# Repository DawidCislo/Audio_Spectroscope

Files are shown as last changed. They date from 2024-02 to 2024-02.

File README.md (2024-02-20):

# Audio_Spectroscope


This is an Audio Spectroscope made without using any kind of programmable devices. It uses over 120 ICs such as operational amplifiers, comparators and logic gates to create the effect you can see in the preview above.

# Theory of operation
The device consists of 11 PCBs, one backplane and 10 display modules. You can find the KiCad project files for the backplane in the 'ASP_Backplane' folder, and files for the display modules in the 'ASP_DIsplay' folder. On the backplane there are 2 3.5mm TRS sockets. Both of them are connected together, and the user can plug the source to one of the sockets, and headphones or speakers to the other, so there's no need to use a splitter. Next using a set of jumpers (JP1, JP2, JP3) the user can use either the left, right or both channels as the input for the spectroscope. Jumpers feed into a preamp with user-adjustable gain (U4A), so both quitet and loud listeners can see the spectroscope work. The series shottky diode (D4) protects the preamp from voltage spikes coming from the audio input and can be omitted.

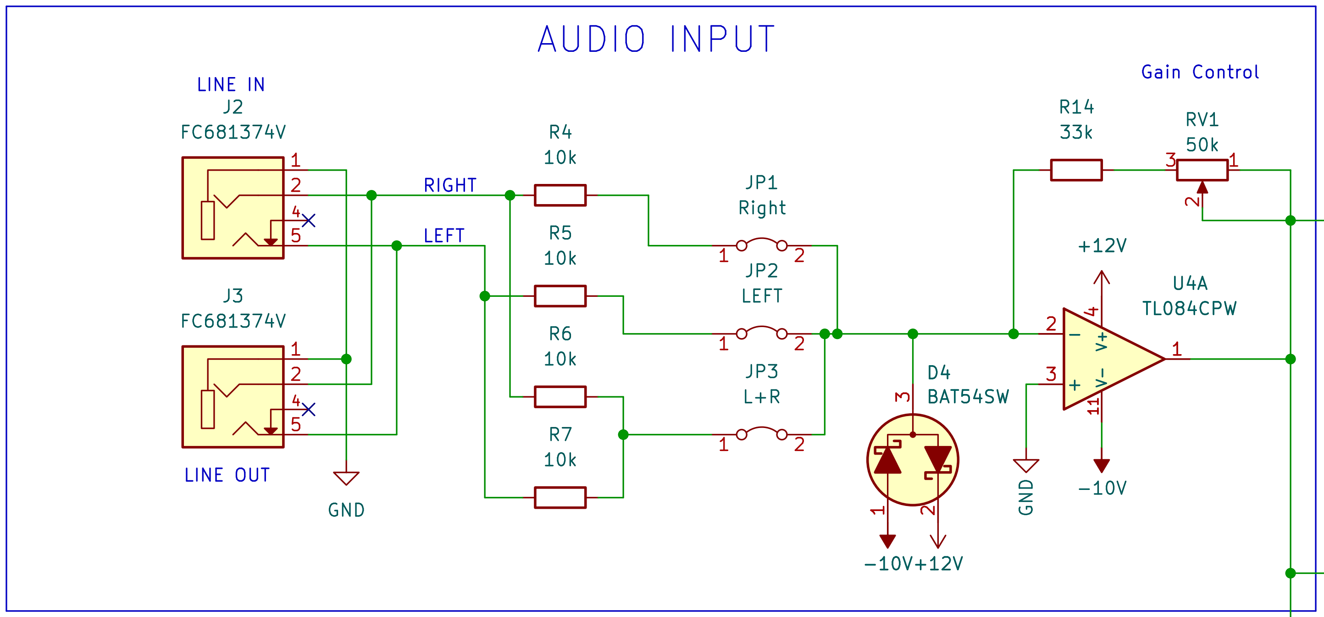
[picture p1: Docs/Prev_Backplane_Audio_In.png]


The preamp feeds into 10 active band-pass filters that separate the audio signals into different bands. Those bands are: 32Hz, 63Hz, 125Hz, 250Hz, 500Hz, 1kHz, 2kHz, 4kHz, 8kHz and 16kHz. Each band is connected to a separate display module connector.

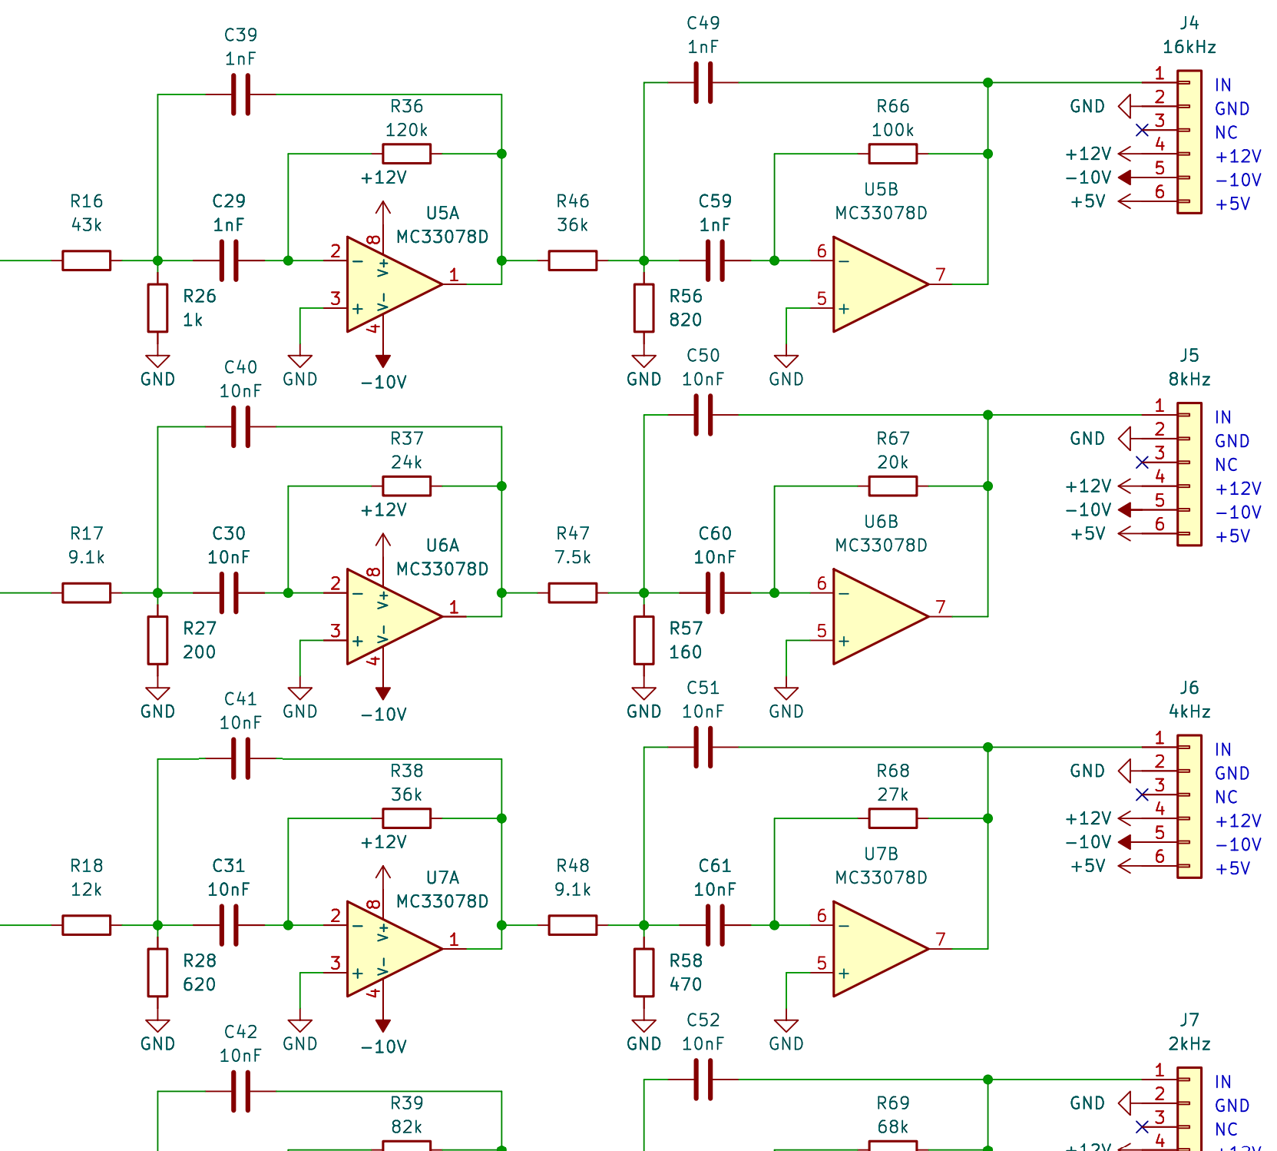
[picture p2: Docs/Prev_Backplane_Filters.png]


The backplane also has a power connector (5.5/2.1mm DC jack, center positive), for use with an external 12V 1A power supply, with a switch and some basic overvoltage protection. You can save on component cost by replacing the power switch (SW1) with a jumper, so that the device will always be on, and you can omit the TVS diode (D1) and replace both the fuse (F1) and reverse-circuit protection diode (D3) with a short - this will reduce resistance to voltage spikes coming from the external power supply.

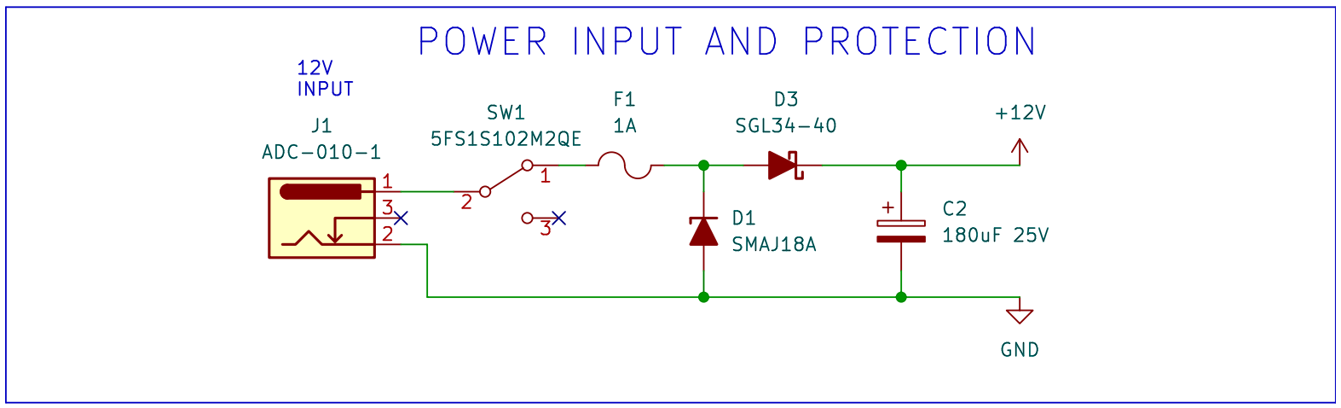
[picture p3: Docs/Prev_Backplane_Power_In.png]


Device uses an LM2576T for generating the 5V rail, the circuit has a voltage divider with resistor values calculated for an adjustable version of LM2576T, but if a fixed 5V version of this IC is available, simply omit R13 during assembly and replace R12 with a short.

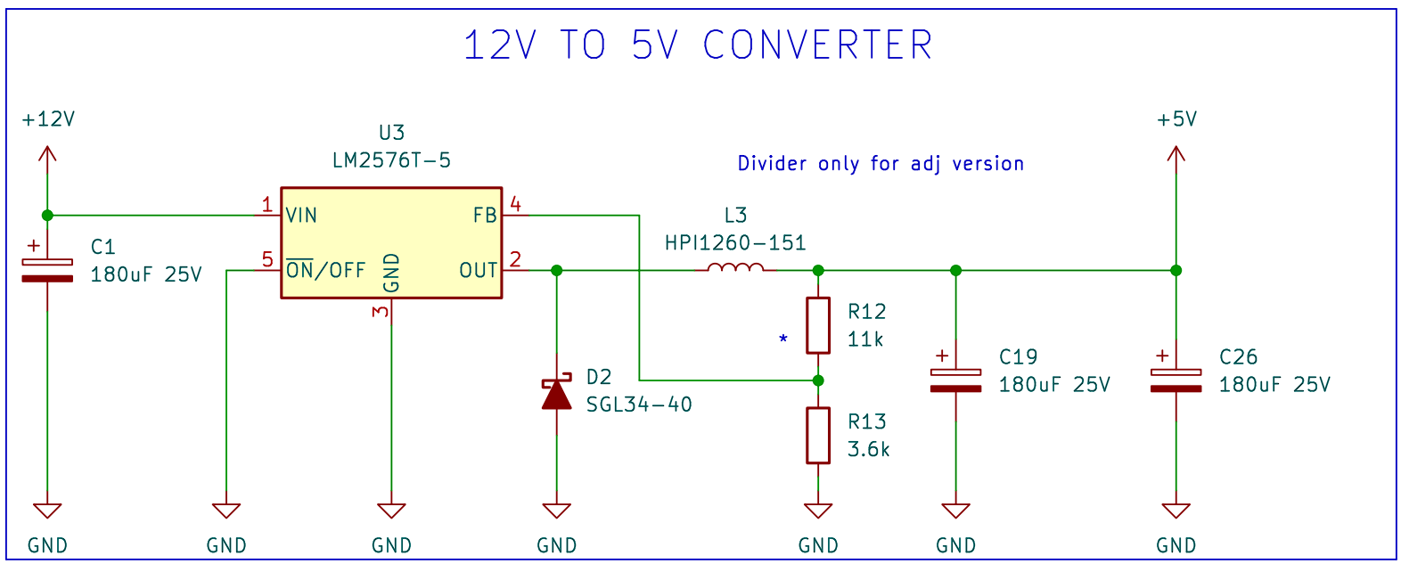
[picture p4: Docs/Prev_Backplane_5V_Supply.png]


Backplane also has a -10V source built using an MC34063 multi-purpose controller. Due to low current draw on the -10V rail, internal switching transistor is sufficient, simplifying the design.

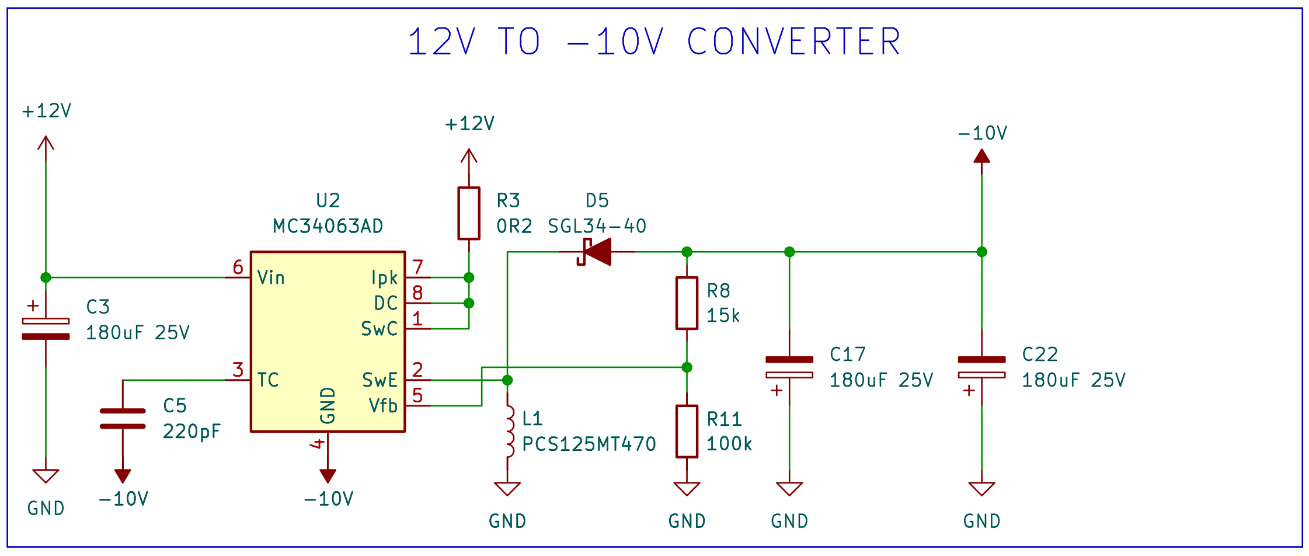
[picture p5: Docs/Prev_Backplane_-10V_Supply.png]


Each display module has two peak detectors connected in series. The first detector made up of U3A, D1 and U3B has a smaller hold capacitor C12 and it's quickly discharged by R34. Output of this peak detector will show the current amplitude of a filtered audio signal. Next peak detector (U3C, D2 U3D) has a larger hold capacitor and it does not have a discharge resistor. Since it's connected to U3D and D2 it will still discharge, because of non-zero leakage currents of those components. Output of this slow peak detector will show the maximum amplitude of the audio signal and hold it there for a short while.

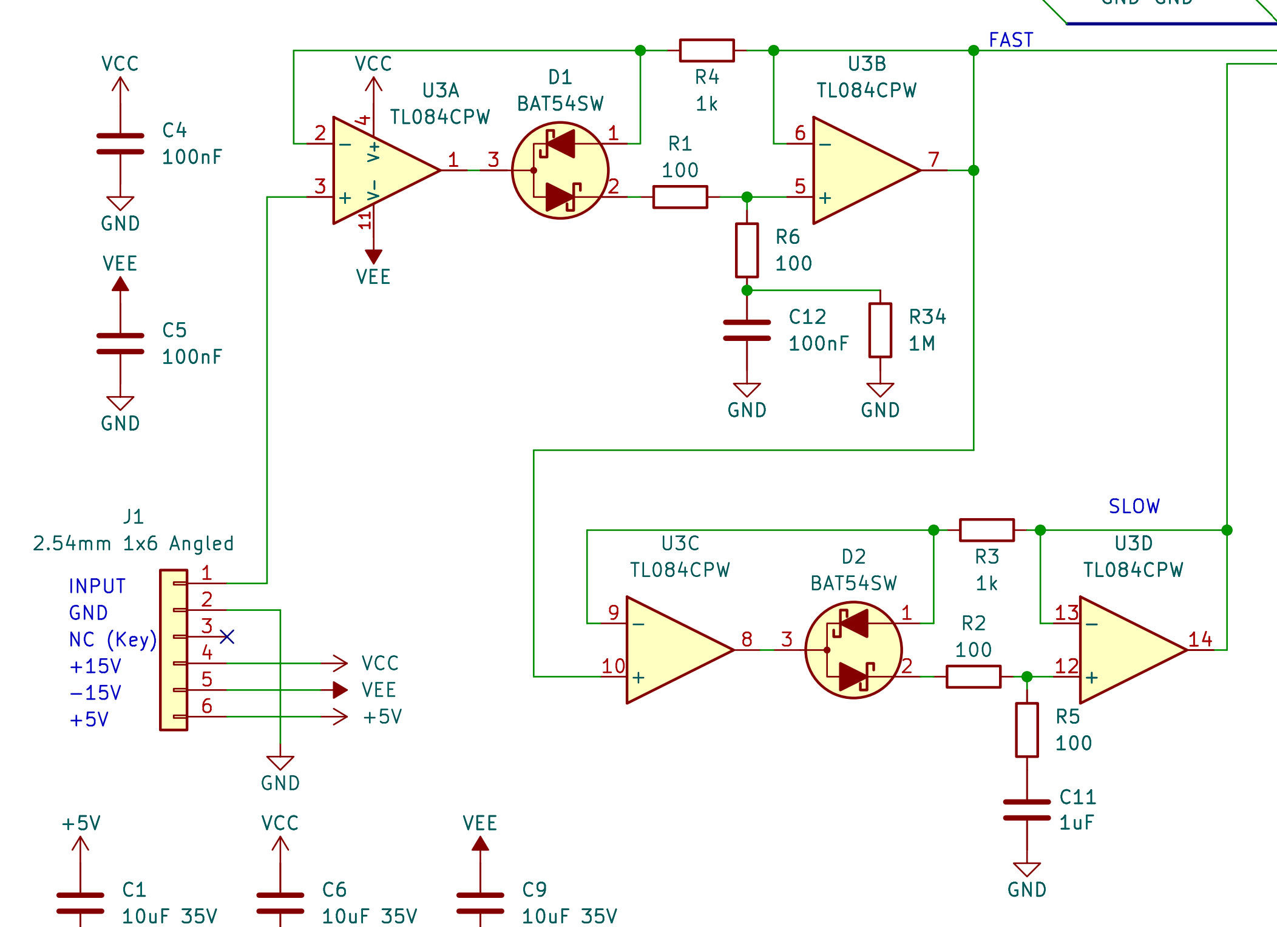
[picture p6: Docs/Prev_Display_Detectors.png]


Both the fast and slow peak detector outputs are connected to 12 comparators each. Reference levels for the comparators are set by a long voltage divider in the middle. If a voltage on the input line is higher than the reference voltage set by the resistors, a comparator pulls the output low (since it has an open-collector output). In effect, the higher the voltage on the input line, the more comparators are switched off, and the more of their outputs have a logic low. On the fast side the comparators connect to logic NOT gates through some simple Resistor-Diode level shifter. On the slow side the comparators feed through voltage level shifters into Ex-OR gates. Each Ex-Or gate is connected to both it's own comparator, and the next comparator. If both of the comparator outputs are the same, the gate's output is low. Only in a situation, when the current level is different from the next one, the gate has a logic 1 on its output. As a result, for example, the fast side outputs '000001111111' while the slow side wil only output '000001000000'. 

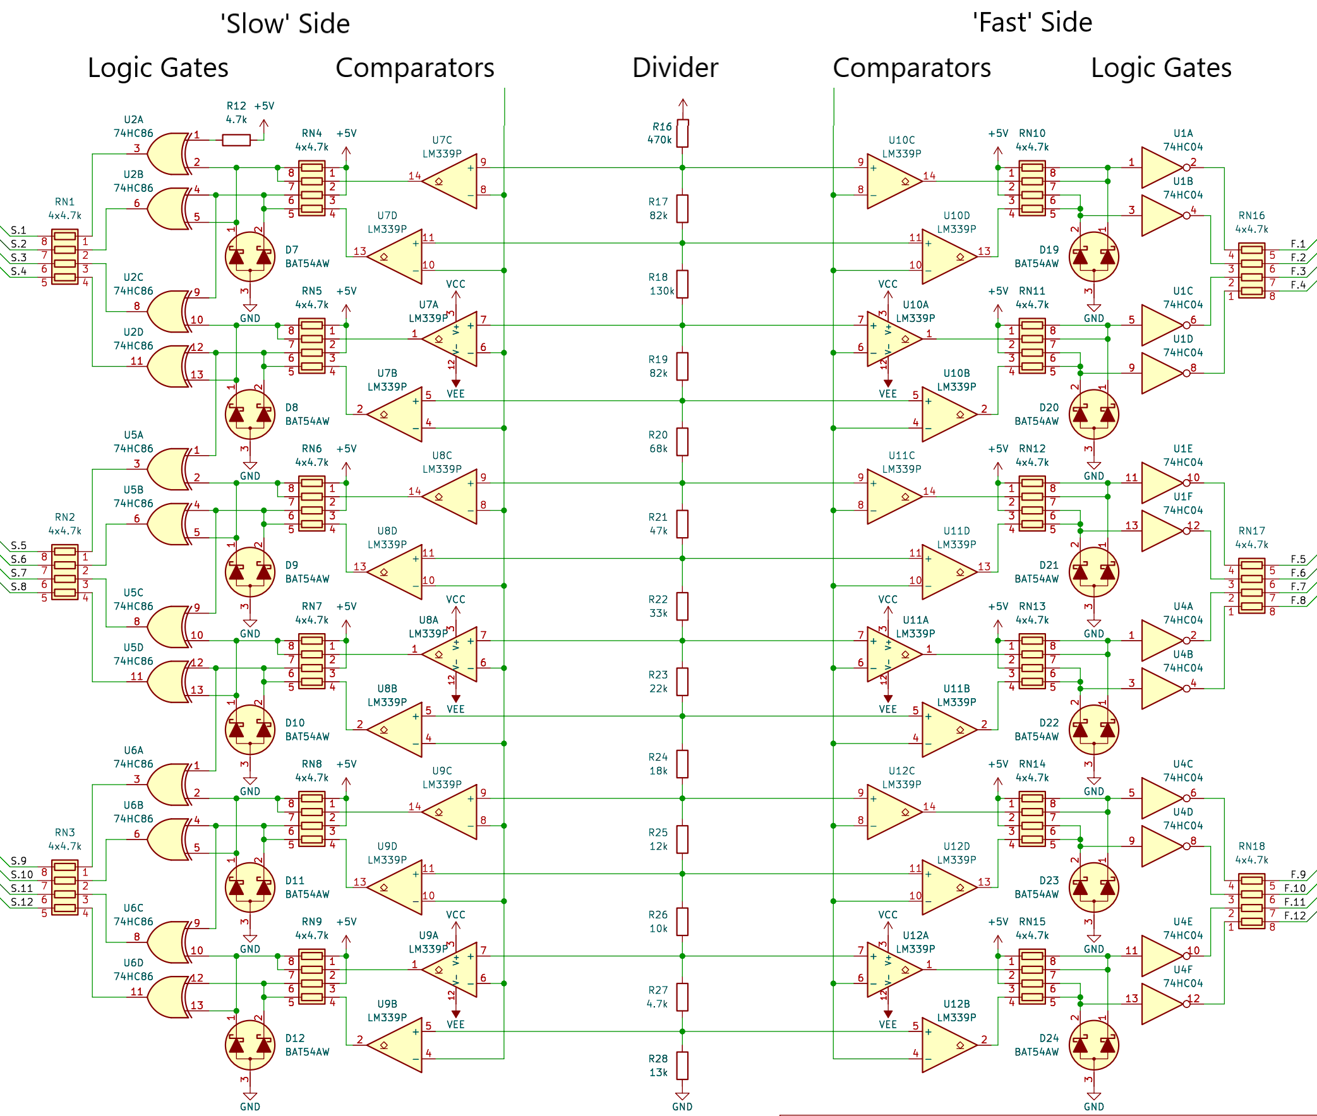
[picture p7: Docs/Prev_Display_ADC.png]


The LEDs are driven by a pair of transistors each (Q2, Q3, Q4 ...). One transistor is controlled by the slow side, while the other one is controlled by the fast side. Transistors are connected in such a way, that either one can independently turn the LED on. Current of the LEDs is set by the series resistors (R8, R9, R10 ...), increasing the value of these resistors decreases the brightness of the LED, and reducing the value increases it. Different LEDs from different manufacturers might need adjustment of these resistor values to achieve a matching brightness for different colors. During the assembly of the first prototype I bought new red and green LEDs, but used old yellow LEDs that I had in stock. Since the old LEDs were much dimmer than the new ones, I used a lower value of resistance for yellow LEDs. Results may vary for your LEDs and it's much better to check them before soldering all 10 display modules.

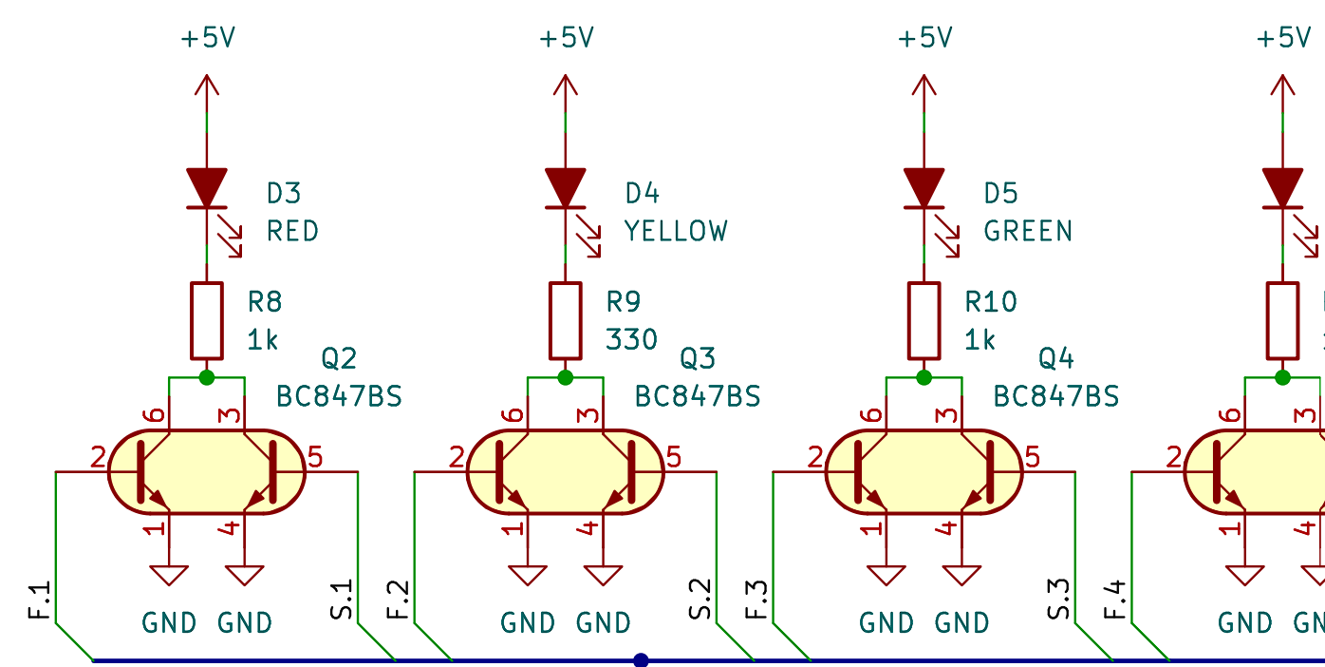
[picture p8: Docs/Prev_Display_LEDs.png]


#  Assembly tips and troubleshooting
>[!CAUTION]
>This device is ***VERY CHALLENGING TO ASSEMBLE*** There is a lot of small and hard to solder components (0603, TSSOP with 0.65mm pin pitch 4x0603 resistor networks, SOT-363s) packed very close together. On top of that there's over 1200 components to solder in total, and it will take very long time to assemble.
I recommend testing every PCB before connecting them together:
- Display modules: Connect all the supply rails on the angled connector to a corresponding voltage source, preferably use a multi-rail adjustable power supply. Next, connect the input of the display module to a potentiometer, generating a voltage between 0V and 5V. See if all the LEDs light up. Next rapidly turn the potentiometer down and see if all the LEDs light up as the slow peak detector discharges. If you see LEDs that are permamently off, check the series resistors and dual transistors next to the LEDs. If whole 4x or 6x sections refuse to light up or stay always on, check the ICs. If single LEDs stay on or light up in the wrong order, check the resistor networks. If the whole module refuses to light up, check the peak detector.
- Backplane: Check if there is no short on any power rails by sticking two pieces of wire into any of the display module connector and using a multimeter in a continuity mode. If there are no shorts on any of the rails, connect the external power supply, and then using the same 2 wires and a multimeter, now in voltage mode, check if all the supply rails have a correct voltage. Note: having a slightly lower voltage on both the 12V and -10V is still fine and will not prevent the device from wirking correctly.
Only after each PCB is thoroughly tested, you can connect them all together and see if the device really works. Display modules are packed very close together, so make sure that the LEDs don't short to the neighbouring modules. Now connect the audio cable and use an online tone generator ([like this one](https://www.szynalski.com/tone-generator/)) to test if the band-pass filters are working correctly.

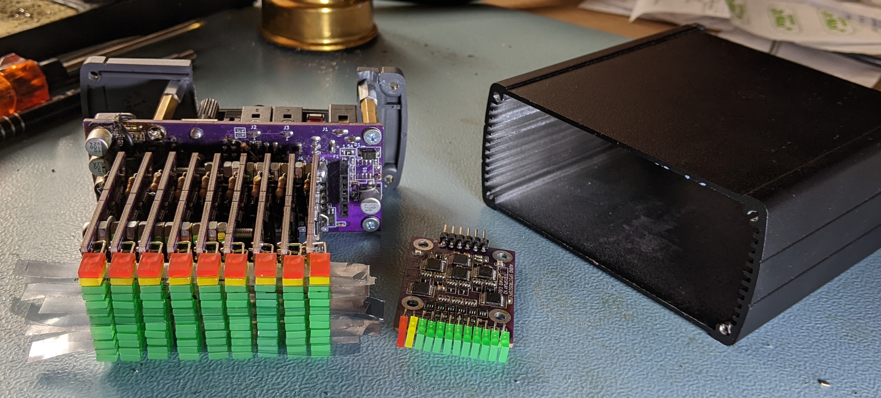
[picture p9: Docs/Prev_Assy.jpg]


If everything is working as it should, you can go ahead and assemble it together. I used a set of long M3 screws to tie all the display modules together and used a [TEKAL 31.29](https://www.tme.eu/pl/details/tekal31.29/obudowy-z-panelem/teko/tekal-31-29/) case. I've used thin strips of gray foil to stop light from bleeding between LEDs. In this preview you can see the first prototype, which had several major errors - they have been fixed and the files shared in this repository should be all good. On the animated preview and here, only 9 display modules are fitted - last module is broken and I can't figure out what exactly is wrong with it.
> [!NOTE]
> All those ICs packed so close together get pretty hot, and the hotter the circuit gets, the larger leakage currents are, and the faster the 'slow' peak detector falls. Drill a few ventillation holes or use a thermal pad to help dissipate the heat.

## Other information 
The project files were last edited in KiCad 7.0.9 and can be opened by any version that's newer than that.

Symbols and footprints used to create this project are part of my library, you can get it and use it for your projects here: [alternatekicadlibrary.com](https://alternatekicadlibrary.com/).

All the content within this repository is dedicated to the public domain under the [CC0 1.0 Universal (CC0 1.0) Public Domain Dedication](https://creativecommons.org/publicdomain/zero/1.0/).

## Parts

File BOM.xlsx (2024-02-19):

No | Component type | Value | Amount | Part Number | Note
1 | MLCC | 100nF 0603 | 166 | C0603C104J3RAC7867 (https://www.mouser.pl/ProductDetail/KEMET/C0603C104J3RAC7867) | Voltage rating 25V or higher
2 | MLCC | 1uF 0603 | 10 | CC0603KRX5R8BB105 (https://www.mouser.pl/ProductDetail/YAGEO/CC0603KRX5R8BB105?qs=BKNoF%2F0xMNuZVooGAHMQbg%3D%3D) | Voltage rating 16V or higher
3 | MLCC | 10uF 1206 | 30 | 1206DD106MAT2A (https://www.mouser.pl/ProductDetail/KYOCERA-AVX/1206DD106MAT2A?qs=lhAPX%252BE7qEaaGz%2FHFoBa1A%3D%3D) | Voltage rating 25V or higher
4 | MLCC | 10nF 0603 | 16 | 06035C103KAT2A (https://www.mouser.pl/ProductDetail/KYOCERA-AVX/06035C103KAT2A) | Voltage rating 25V or higher
5 | MLCC | 1uF 0805 | 8 | 08053C105KAT2A (https://www.mouser.pl/ProductDetail/KYOCERA-AVX/08053C105KAT2A) | Voltage rating 25V or higher
6 | MLCC | 1nF 0603 | 4 | 06035C102M4T2A (https://www.mouser.pl/ProductDetail/KYOCERA-AVX/06035C102M4T2A) | Voltage rating 25V or higher
7 | MLCC | 220pF 0603 | 1 | 06035A221JAT4A (https://www.mouser.pl/ProductDetail/KYOCERA-AVX/06035A221JAT4A?qs=WmCxkUxNecTiAawuxZlelw%3D%3D) | Voltage rating 25V or higher
8 | Electrolytic SMD | 180uF 25V | 7 | EEE-FNE181XUL (https://www.mouser.pl/ProductDetail/Panasonic/EEE-FNE181XUL?qs=vmHwEFxEFR9HMUvcXfbSpA%3D%3D) | Only 6.3x7.7mm size will fit
9 | Resistor | 130k 0603 | 12 | RT0603FRE07130KL (https://www.mouser.pl/ProductDetail/YAGEO/RT0603FRE07130KL?qs=4CyHz7GXqSgvj%252BNgfeo8XA%3D%3D) | Preferable 1% tolerance
10 | Resistor | 100R 0603 | 40 | CR0603-JW-101ELF (https://www.mouser.pl/ProductDetail/Bourns/CR0603-JW-101ELF?qs=jAUlru4btJFOerhakJcyhQ%3D%3D)
11 | Resistor | 10k 0603 | 15 | CMP0603AFX-1002ELF (https://www.mouser.pl/ProductDetail/Bourns/CMP0603AFX-1002ELF?qs=TiOZkKH1s2Q14lKL9rbzLg%3D%3D) | Preferable 1% tolerance
12 | Resistor | 12k 0603 | 10 | CR0603-FX-1202ELF (https://www.mouser.pl/ProductDetail/Bourns/CR0603-FX-1202ELF?qs=e7cxVwPieuqIXTNAyS26aw%3D%3D) | Preferable 1% tolerance
13 | Resistor | 13k 0603 | 10 | CR0603-FX-1302ELF (https://www.mouser.pl/ProductDetail/Bourns/CR0603-FX-1302ELF?qs=e7cxVwPieupfaEpwRfHteQ%3D%3D) | Preferable 1% tolerance
14 | Resistor | 18k 0603 | 12 | CR0603-FX-1802ELF (https://www.mouser.pl/ProductDetail/Bourns/CR0603-FX-1802ELF?qs=zx2075yZkZIiZ9iXil5T4w%3D%3D) | Preferable 1% tolerance
15 | Resistor | 1M 0603 | 10 | CR0603-FX-1004ELF (https://www.mouser.pl/ProductDetail/Bourns/CR0603-FX-1004ELF?qs=e7cxVwPieuqVG4NBrfqH%252BA%3D%3D)
16 | Resistor | 1k 0805 | 110 | CMP0805QFX-1001ELF (https://www.mouser.pl/ProductDetail/Bourns/CMP0805QFX-1001ELF?qs=8Wlm6%252BaMh8Q2Rm3nuB%252BTSQ%3D%3D)
17 | Resistor | 1k 0603 | 22 | CR0603-FX-1001ELF (https://www.mouser.pl/ProductDetail/Bourns/CR0603-FX-1001ELF?qs=K5ddiUFZPT4YQXF75Ui8dQ%3D%3D) | Preferable 1% tolerance
18 | Resistor | 22k 0603 | 11 | CR0603-FX-2202ELF (https://www.mouser.pl/ProductDetail/Bourns/CR0603-FX-2202ELF?qs=zx2075yZkZK8KV7Pk1JasQ%3D%3D) | Preferable 1% tolerance
19 | Resistor | 330R 0805 | 10 | CR0805-JW-331ELF (https://www.mouser.pl/ProductDetail/Bourns/CR0805-JW-331ELF?qs=%252BcBkmVQIZ2RP8aX1cRFLQQ%3D%3D)
20 | Resistor | 33k 0603 | 12 | CR0603-FX-3302ELF (https://www.mouser.pl/ProductDetail/Bourns/CR0603-FX-3302ELF?qs=I4suiNu8FYCWxaWbJ3KE%252Bw%3D%3D) | Preferable 1% tolerance
21 | Resistor | 4.7k 0603 | 20 | CR0603-FX-4701ELF (https://www.mouser.pl/ProductDetail/Bourns/CR0603-FX-4701ELF?qs=CCIlxZRRv7jGwxSydcgiTA%3D%3D) | Preferable 1% tolerance
22 | Resistor | 470k 0603 | 10 | RC0603FR-07470KL (https://www.mouser.pl/ProductDetail/YAGEO/RC0603FR-07470KL?qs=gt6vzsuosg0YdkYcPnlfQQ%3D%3D) | Preferable 1% tolerance
23 | Resistor | 47k 0603 | 10 | CR0603-FX-4702ELF (https://www.mouser.pl/ProductDetail/Bourns/CR0603-FX-4702ELF?qs=CCIlxZRRv7h9SmHwXOyFMw%3D%3D) | Preferable 1% tolerance
24 | Resistor | 68k 0603 | 11 | CR0603-FX-6802ELF (https://www.mouser.pl/ProductDetail/Bourns/CR0603-FX-6802ELF?qs=0nF2VnfAjXn2ioiAKKtc%2Fg%3D%3D) | Preferable 1% tolerance
25 | Resistor | 9.1k 0603 | 4 | CR0603-JW-912ELF (https://www.mouser.pl/ProductDetail/Bourns/CR0603-JW-912ELF)
26 | Resistor | 24k 0603 | 4 | CR0603-JW-243ELF (https://www.mouser.pl/ProductDetail/Bourns/CR0603-JW-243ELF)
27 | Resistor | 100k 0603 | 3 | CR0603-JW-104ELF (https://www.mouser.pl/ProductDetail/Bourns/CR0603-JW-104ELF)
28 | Resistor | 43k 0603 | 3 | CR0603-FX-4302ELF (https://www.mouser.pl/ProductDetail/Bourns/CR0603-FX-4302ELF)
29 | Resistor | 36k 0603 | 3 | CR0603-FX-3602ELF (https://www.mouser.pl/ProductDetail/Bourns/CR0603-FX-3602ELF)
30 | Resistor | 15k 0603 | 2 | CR0603-FX-1502ELF (https://www.mouser.pl/ProductDetail/Bourns/CR0603-FX-1502ELF?qs=sGAEpiMZZMtlubZbdhIBIJoX7P5Bll7aijQ7WLBB5o0%3D)
31 | Resistor | 11k 0603 | 2 | CR0603-FX-1102ELF (https://www.mouser.pl/ProductDetail/Bourns/CR0603-FX-1102ELF?qs=sGAEpiMZZMtlubZbdhIBIJoX7P5Bll7awqQ9N9RUQg0%3D)
32 | Resistor | 620R 0603 | 2 | CR0603-JW-621ELF (https://www.mouser.pl/ProductDetail/Bourns/CR0603-JW-621ELF?qs=sGAEpiMZZMtlubZbdhIBIN4pzcyTCT7wZQcdO7o40gI%3D)
33 | Resistor | 820R 0603 | 2 | CR0603-JW-821ELF (https://www.mouser.pl/ProductDetail/Bourns/CR0603-JW-821ELF?qs=sGAEpiMZZMtlubZbdhIBIN4pzcyTCT7wtOHvIf3yKE0%3D)
34 | Resistor | 1.6k 0603 | 2 | CR0603-JW-162ELF (https://www.mouser.pl/ProductDetail/Bourns/CR0603-JW-162ELF?qs=sGAEpiMZZMtlubZbdhIBILRoc98ORTtjVuyENSnixOs%3D)
35 | Resistor | 330R 0603 | 2 | CR0603-JW-331ELF (https://www.mouser.pl/ProductDetail/Bourns/CR0603-JW-331ELF?qs=sGAEpiMZZMtlubZbdhIBIAkADrRUF3rw2IjtieDa238%3D)
36 | Resistor | 51k 0603 | 2 | CR0603-FX-5102ELF (https://www.mouser.pl/ProductDetail/Bourns/CR0603-FX-5102ELF?qs=sGAEpiMZZMtlubZbdhIBIMinHFTiNSf6vHPcqpI5Tls%3D)
37 | Resistor | 20k 0603 | 2 | CR0603-FX-2002ELF (https://www.mouser.pl/ProductDetail/Bourns/CR0603-FX-2002ELF)
38 | Resistor | 0R2 2512 | 1 | RL2512FK-070R2L (https://www.mouser.pl/ProductDetail/YAGEO/RL2512FK-070R2L?qs=sGAEpiMZZMtlubZbdhIBILzAkmRldA9hMBS51BNaaM8%3D)
39 | Resistor | 3.6k 0603 | 1 | CR0603-JW-362ELF (https://www.mouser.pl/ProductDetail/Bourns/CR0603-JW-362ELF?qs=sGAEpiMZZMtlubZbdhIBILRoc98ORTtjFdw8hysAwf0%3D)
40 | Resistor | 30k 0603 | 1 | CR0603-JW-303ELF (https://www.mouser.pl/ProductDetail/Bourns/CR0603-JW-303ELF)
41 | Resistor | 56k 0603 | 1 | CR0603-FX-5602ELF (https://www.mouser.pl/ProductDetail/Bourns/CR0603-FX-5602ELF?qs=sGAEpiMZZMtlubZbdhIBIMinHFTiNSf6IktMs0einTA%3D)
42 | Resistor | 200R 0603 | 1 | CR0603-JW-201ELF (https://www.mouser.pl/ProductDetail/Bourns/CR0603-JW-201ELF?qs=sGAEpiMZZMtlubZbdhIBILRoc98ORTtjLu2xS4ECIXc%3D)
43 | Resistor | 2k 0603 | 1 | RT0603BRD072KL (https://www.mouser.pl/ProductDetail/YAGEO/RT0603BRD072KL?qs=sGAEpiMZZMtlubZbdhIBICmCO3QN7ITcpbXvNpp38Tc%3D)
44 | Resistor | 430R 0603 | 1 | CR0603-JW-431ELF (https://www.mouser.pl/ProductDetail/Bourns/CR0603-JW-431ELF)
45 | Resistor | 120k 0603 | 1 | CR0603-JW-124ELF (https://www.mouser.pl/ProductDetail/Bourns/CR0603-JW-124ELF?qs=sGAEpiMZZMtlubZbdhIBILRoc98ORTtjPMp5CH4BPAg%3D)
46 | Resistor | 82k 0603 | 11 | CR0603-FX-8202ELF (https://www.mouser.pl/ProductDetail/Bourns/CR0603-FX-8202ELF)
47 | Resistor | 160k 0603 | 1 | CR0603-JW-164ELF (https://www.mouser.pl/ProductDetail/Bourns/CR0603-JW-164ELF)
48 | Resistor | 62k 0603 | 1 | CR0603-JW-623ELF (https://www.mouser.pl/ProductDetail/Bourns/CR0603-JW-623ELF?qs=sGAEpiMZZMtlubZbdhIBIN4pzcyTCT7w8jMPA58DmJY%3D)
49 | Resistor | 7.5k 0603 | 1 | RC0603FR-077K5L (https://www.mouser.pl/ProductDetail/YAGEO/RC0603FR-077K5L)
50 | Resistor | 6.8k 0603 | 1 | CR0603-FX-6801ELF (https://www.mouser.pl/ProductDetail/Bourns/CR0603-FX-6801ELF?qs=sGAEpiMZZMtlubZbdhIBIMinHFTiNSf6XYwxKUI8ZAU%3D)
51 | Resistor | 160R 0603 | 1 | CR0603-JW-161ELF (https://www.mouser.pl/ProductDetail/Bourns/CR0603-JW-161ELF?qs=sGAEpiMZZMtlubZbdhIBILRoc98ORTtjcMTpW71rJlo%3D)
52 | Resistor | 470R 0603 | 1 | CR0603-JW-471ELF (https://www.mouser.pl/ProductDetail/Bourns/CR0603-JW-471ELF?qs=sGAEpiMZZMtlubZbdhIBIN4pzcyTCT7wAWvNAcavl80%3D)
53 | Resistor | 750R 0603 | 1 | CR0603-JW-751ELF (https://www.mouser.pl/ProductDetail/Bourns/CR0603-JW-751ELF)
54 | Resistor | 680R 0603 | 1 | CR0603-JW-681ELF (https://www.mouser.pl/ProductDetail/Bourns/CR0603-JW-681ELF?qs=sGAEpiMZZMtlubZbdhIBIN4pzcyTCT7wXIboaCMQ32U%3D)
55 | Resistor | 1.3k 0603 | 1 | CR0603-JW-132ELF (https://www.mouser.pl/ProductDetail/Bourns/CR0603-JW-132ELF?qs=sGAEpiMZZMtlubZbdhIBILRoc98ORTtjPCkDSc43JvE%3D)
56 | Resistor | 270R 0603 | 1 | CR0603-JW-271ELF (https://www.mouser.pl/ProductDetail/Bourns/CR0603-JW-271ELF?qs=sGAEpiMZZMtlubZbdhIBILRoc98ORTtjbpi8WyVcbc4%3D)
57 | Resistor | 510R 0603 | 1 | CR0603-JW-511ELF (https://www.mouser.pl/ProductDetail/Bourns/CR0603-JW-511ELF?qs=sGAEpiMZZMtlubZbdhIBIN4pzcyTCT7wEfxobntPQzY%3D)
58 | Resistor | 27k 0603 | 1 | CR0603-FX-2702ELF (https://www.mouser.pl/ProductDetail/Bourns/CR0603-FX-2702ELF)
59 | Resistor | 39k 0603 | 1 | CR0603-FX-3902ELF (https://www.mouser.pl/ProductDetail/Bourns/CR0603-FX-3902ELF)
60 | Resistor Network | 4x4.7k 4x0603 | 180 | TC164-JR-134K7L (https://www.mouser.pl/ProductDetail/YAGEO/TC164-JR-134K7L?qs=qpJ%252B%252B%252Bdg6p2j%2F7LnTbF68g%3D%3D)
61 | LED | Green 2x5mm | 100 | SSL-LX2573PGD (https://www.mouser.pl/ProductDetail/Lumex/SSL-LX2573PGD)
62 | LED | Yellow 2x5mm | 10 | SSL-LX2573AD (https://www.mouser.pl/ProductDetail/Lumex/SSL-LX2573AD) | original used old yellow LEDs with lower brightness, that's why the current limiting resistor for these is smaller. You might want to check how bright LEDs get and match their brightness by using different resistor values
63 | LED | Red 2x5mm | 10 | SSL-LX2573HD (https://www.mouser.pl/ProductDetail/Lumex/SSL-LX2573HD)
64 | Diode | BAT54SW | 21 | BAT54SW (https://www.mouser.pl/ProductDetail/Diotec-Semiconductor/BAT54SW?qs=OlC7AqGiEDkjmaxI%252BbPoqA%3D%3D)
65 | Diode | BAT54AW | 120 | BAT54AW (https://www.mouser.pl/ProductDetail/Diotec-Semiconductor/BAT54AW?qs=OlC7AqGiEDnaO%252BUPXz848w%3D%3D)
66 | Diode | SMAJ18A | 1 | SMAJ18A-13-F (https://www.mouser.pl/ProductDetail/Diodes-Incorporated/SMAJ18A-13-F?qs=sxN%252BoM2fis92ZCckKJ8sjg%3D%3D)
67 | Diode | SGL34-40 | 3 | SGL34-40 (https://www.mouser.pl/c/semiconductors/discrete-semiconductors/diodes-rectifiers/schottky-diodes-rectifiers/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)
68 | Transistor | BC847BS | 120 | BC847BS,115 (https://www.mouser.pl/ProductDetail/Nexperia/BC847BS115?qs=me8TqzrmIYXy2TZEvQyxww%3D%3D) | any dual NPN transistor in SOT-363 package with the same pinout
69 | Fuse | 1A 1206 | 1 | SF-1206FP100-2 (https://www.mouser.pl/ProductDetail/Bourns/SF-1206FP100-2)
70 | DC Socket | ADC-010-1 | 1 | ADC-010-1 (https://www.tme.eu/pl/details/adc-010-1/zlacza-dc/adam-tech/)
71 | Audio Socket | FC681374V | 2 | FC681374V (https://www.tme.eu/en/details/fc681374v/jack-connectors/cliff/)
72 | Connector F | 1x6 2.54mm socket | 10 | ZL262-6SG (https://www.tme.eu/pl/details/zl262-6sg/listwy-i-gniazda-kolkowe/connfly/ds1023-1-6s21/)
73 | Connector M | 1x6 2.54mm angled | 10 | MX-90121-0766 (https://www.tme.eu/pl/details/mx-90121-0766/listwy-i-gniazda-kolkowe/molex/901210766/) | alt: use a generic angled 2.54mm strip and cut it to pieces
74 | Inductor | PCS125MT470 | 1 | PCS125MT470 (https://www.tme.eu/pl/details/pcs125mt470/dlawiki-smd-mocy/viking/)
75 | Inductor | HPI1260-151 | 1 | HPI1260-151 (https://www.tme.eu/pl/details/hpi1260-151/dlawiki-smd-mocy/ferrocore/)
76 | Power Switch | 5FS1S102M2QE | 1 | 5FS1S102M2QE (https://www.tme.eu/pl/details/5fs1s102m2qe/przelaczniki-suwakowe/ninigi/) | alt: use a jumper if you want to keep the device on at all times (the existing switch is hard to reach anyway)
77 | IC | TL084 TSSOP | 14 | TL084IPT (https://www.mouser.pl/ProductDetail/STMicroelectronics/TL084IPT?qs=AHP2kOhVzq81fzf7My4Wdw%3D%3D)
78 | IC | LM339PW | 60 | LM339PWRG3 (https://www.mouser.pl/ProductDetail/Texas-Instruments/LM339PWRG3?qs=C44r%252BX3hXgJy%252BFh%2FxI6fLA%3D%3D)
79 | IC | 74HC04 | 20 | 74HC04PW,118 (https://www.mouser.pl/ProductDetail/Nexperia/74HC04PW118?qs=P62ublwmbi8J%252BGKGG4lxBA%3D%3D)
80 | IC | 74HC86 | 30 | 74HC86PW,118 (https://www.mouser.pl/ProductDetail/Nexperia/74HC86PW118?qs=P62ublwmbi%252BbZONg%2FxuOpg%3D%3D)
81 | IC | 34063 or equiv | 1 | AZ34063UMTR-G1 (https://www.mouser.pl/ProductDetail/Diodes-Incorporated/AZ34063UMTR-G1?qs=FKu9oBikfSmOGMlC%2Fa3O3g%3D%3D)
82 | IC | LM2576T | 1 | LM2576TV-5G (https://www.mouser.pl/ProductDetail/onsemi/LM2576TV-5G?qs=2OtswVQKCOFWqcas%2FMqA%2Fw%3D%3D) | alt: use a fixed 5V version of this IC - you need to remove R13 and replace R12 with a jumper on the backplane PCB
83 | IC | MC33078 | 3 | MC33078DR2G (https://www.mouser.pl/ProductDetail/onsemi/MC33078DR2G?qs=g2rIOKKlpoYMV60UAamqFQ%3D%3D)
84 | Case | Tekal 31.29 | 1 | TEKAL31.29 (https://www.tme.eu/pl/details/tekal31.29/obudowy-z-panelem/teko/tekal-31-29/) | case needs to be modified (drill mounting holes in the back and cut a piece if the plastic to access the back panel, replace front panel with a translucent piece of plastic or leave open)

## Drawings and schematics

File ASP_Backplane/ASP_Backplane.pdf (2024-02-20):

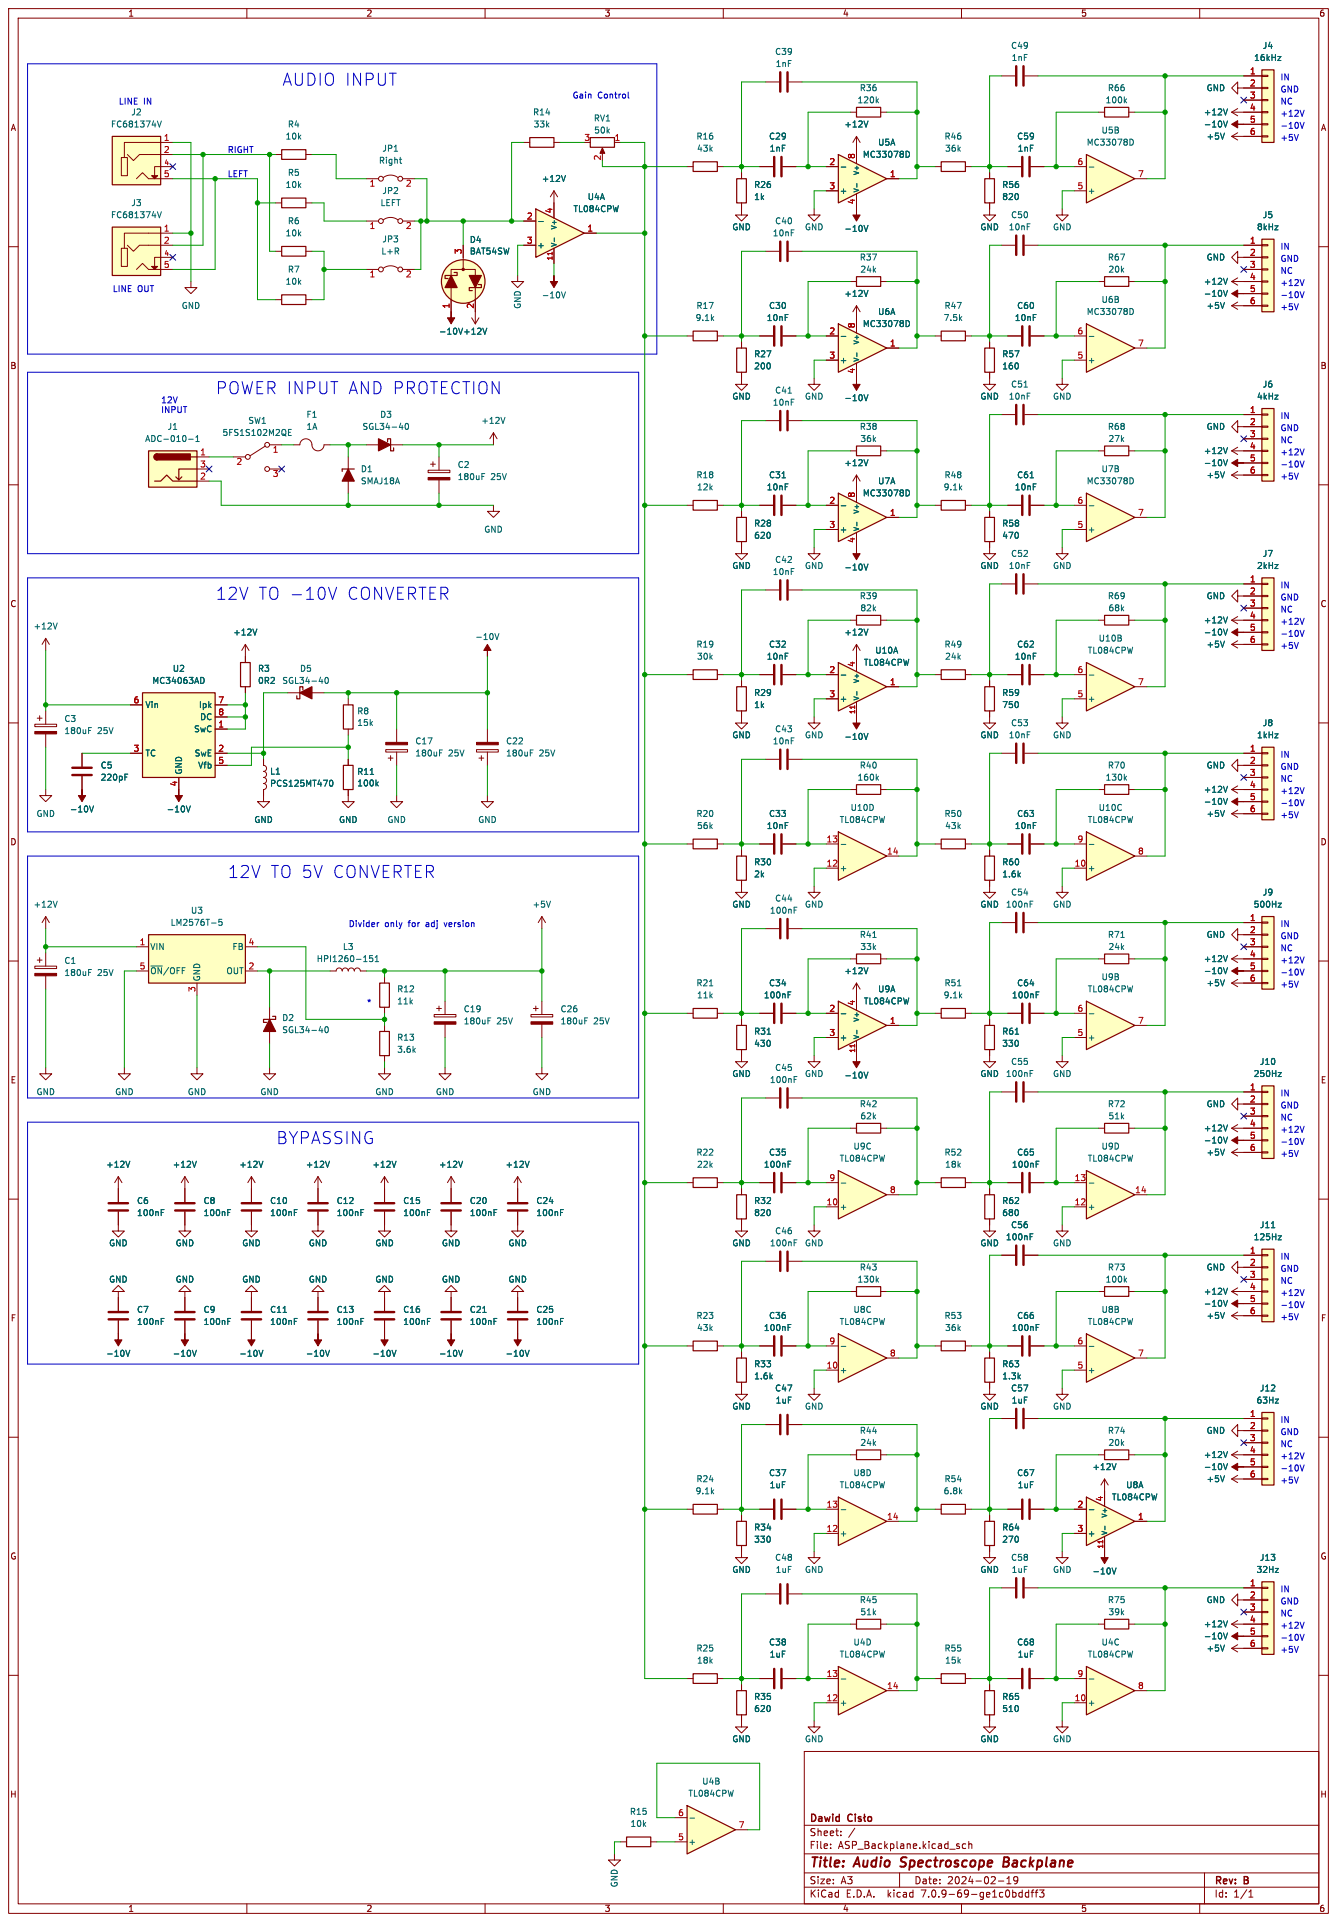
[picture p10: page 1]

IN POWER INPUT AND PROTECTION

Id: 1/1 Title: Audio Spectroscope Backplane

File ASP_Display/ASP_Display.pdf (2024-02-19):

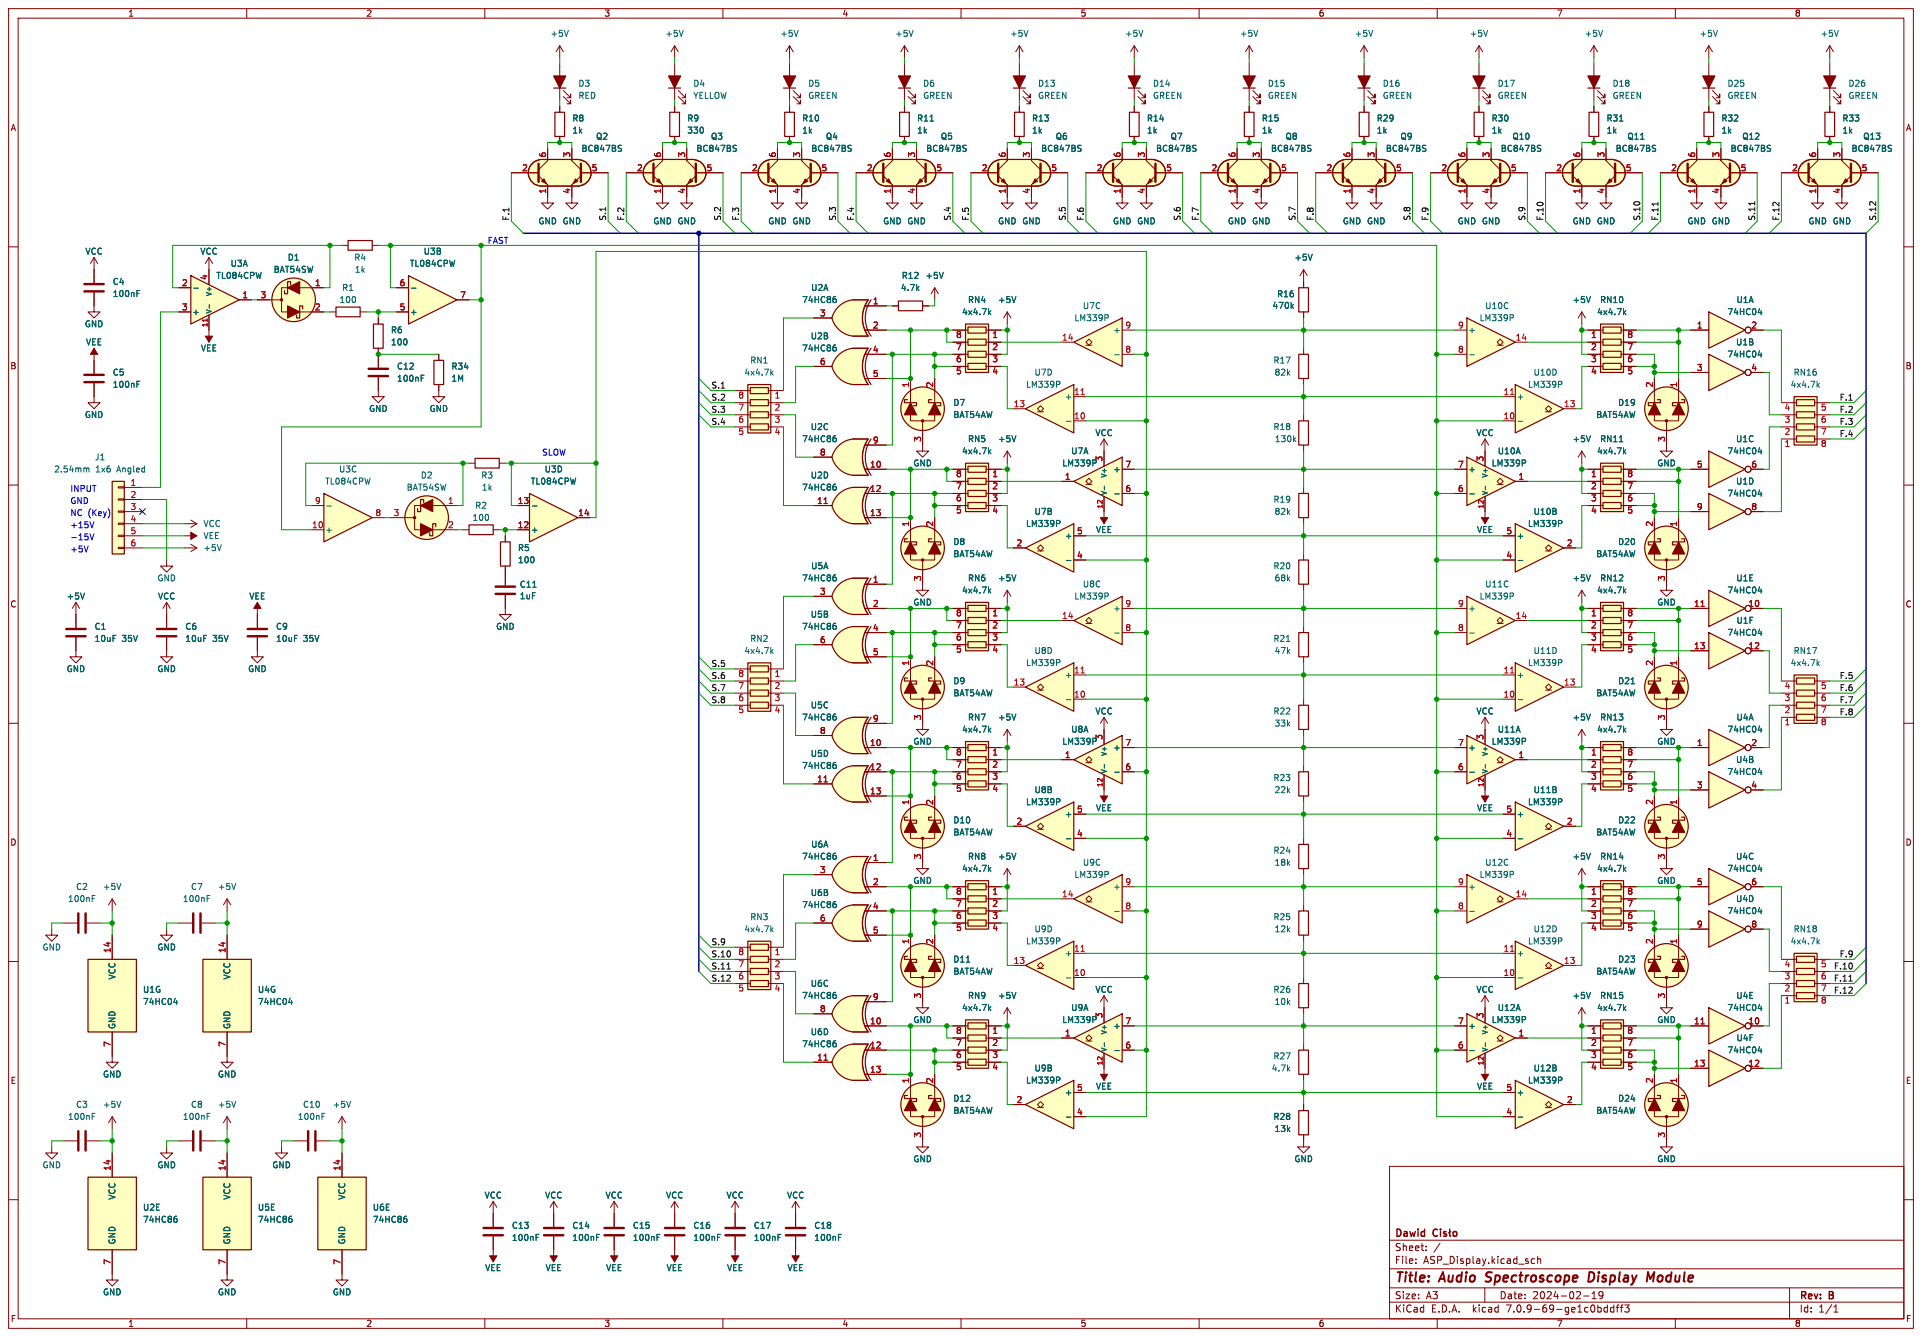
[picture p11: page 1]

7 GND GND GND GND GND
74HC04 VCC 14 GND

Id: 1/1 Title: Audio Spectroscope Display Module

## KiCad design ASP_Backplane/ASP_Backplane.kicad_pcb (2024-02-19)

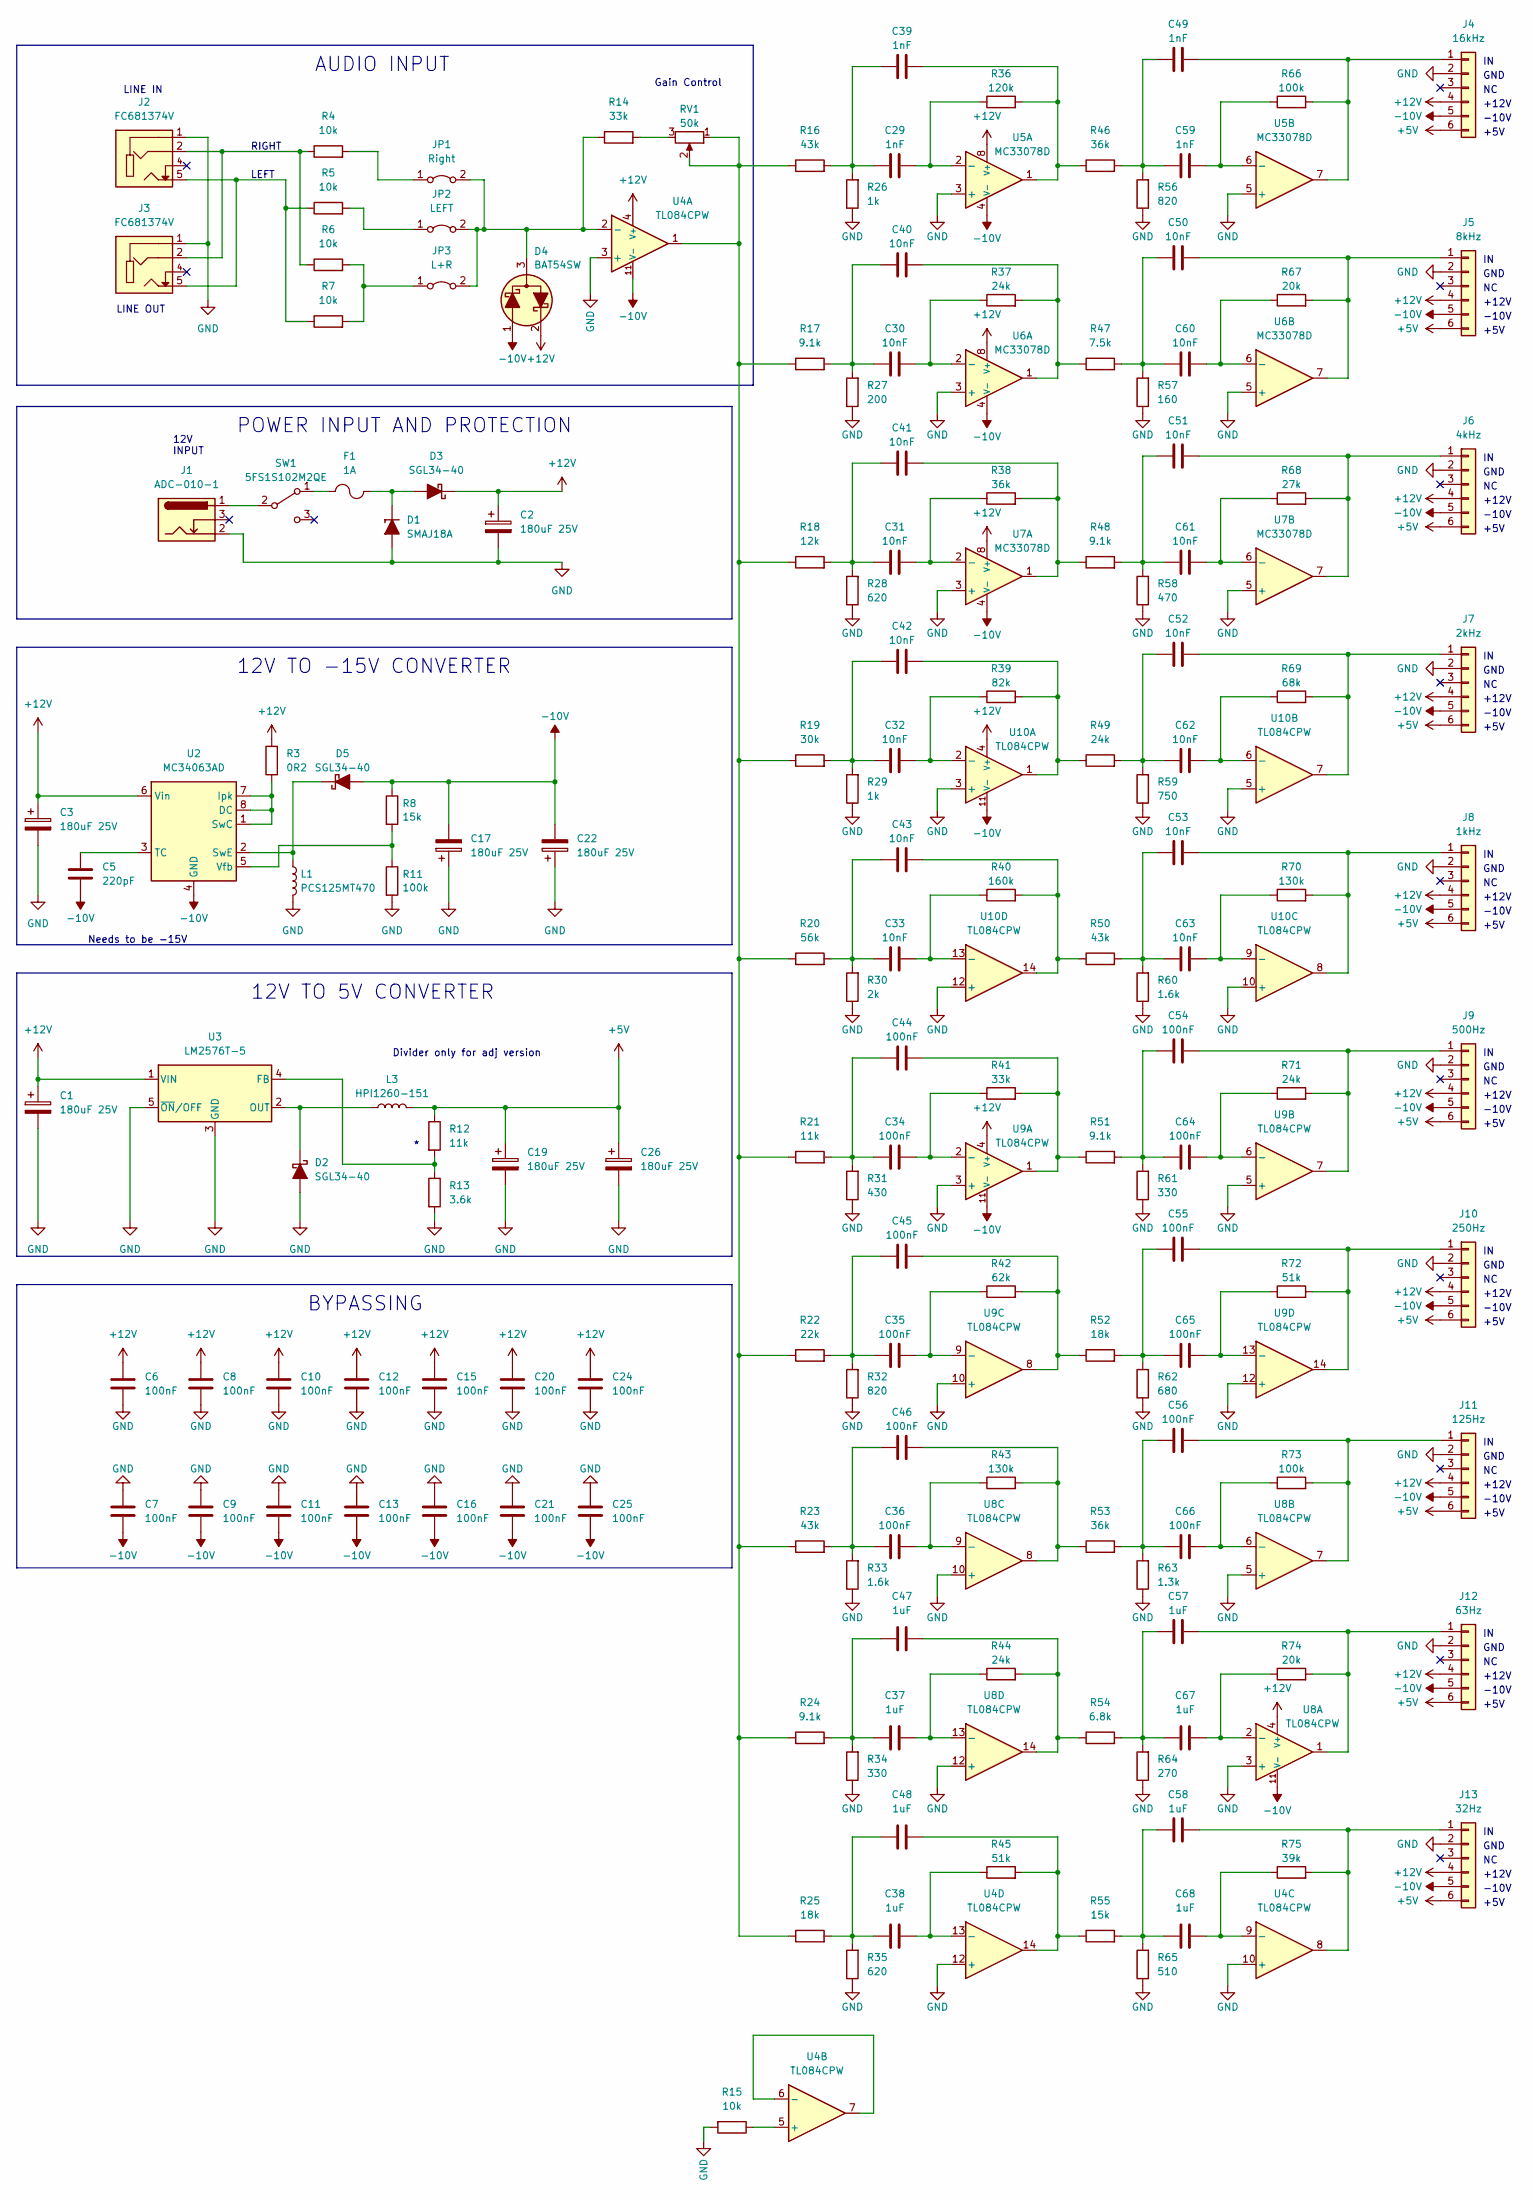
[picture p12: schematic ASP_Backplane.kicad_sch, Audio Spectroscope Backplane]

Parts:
C1, C2, C3, C17, C19, C22, C26: 180uF 25V; CP_Elec_6.3x7.7
C5: 220pF; C_0603_1608Metric
C6, C7, C8, C9, C10, C11, C12, C13, C15, C16, C20, C21, C24, C25, C34, C35, C36, C44, C45, C46, C54, C55, C56, C64, C65, C66: 100nF; C_0603_1608Metric
C29, C39, C49, C59: 1nF; C_0603_1608Metric
C30, C31, C32, C33, C40, C41, C42, C43, C50, C51, C52, C53, C60, C61, C62, C63: 10nF; C_0603_1608Metric
C37, C38, C47, C48, C57, C58, C67, C68: 1uF; C_0805_2012Metric
D1: SMAJ18A; D_SMA
D2, D3, D5: SGL34-40; D_MiniMELF
D4: BAT54SW; SOT-323_SC-70
F1: 1A; Fuse_1206_3216Metric
J1: ADC-010-1
J2, J3: FC681374V
J4: 16kHz; PinSocket_1x06_P2.54mm_Vertical
J5: 8kHz; PinSocket_1x06_P2.54mm_Vertical
J6: 4kHz; PinSocket_1x06_P2.54mm_Vertical
J7: 2kHz; PinSocket_1x06_P2.54mm_Vertical
J8: 1kHz; PinSocket_1x06_P2.54mm_Vertical
J9: 500Hz; PinSocket_1x06_P2.54mm_Vertical
J10: 250Hz; PinSocket_1x06_P2.54mm_Vertical
J11: 125Hz; PinSocket_1x06_P2.54mm_Vertical
J12: 63Hz; PinSocket_1x06_P2.54mm_Vertical
J13: 32Hz; PinSocket_1x06_P2.54mm_Vertical
JP1: Right; PinHeader_1x02_P2.54mm_Vertical
JP2: LEFT; PinHeader_1x02_P2.54mm_Vertical
JP3: L+R; PinHeader_1x02_P2.54mm_Vertical
L1: PCS125MT470; L_12x12mm_H6mm
L3: HPI1260-151; L_Wuerth_HCI-1365
R3: 0R2; R_2512_6332Metric
R4, R5, R6, R7, R15: 10k; R_0603_1608Metric
R8, R55: 15k; R_0603_1608Metric
R11, R66, R73: 100k; R_0603_1608Metric
R12, R21: 11k; R_0603_1608Metric
R13: 3.6k; R_0603_1608Metric
R14, R41: 33k; R_0603_1608Metric
R16, R23, R50: 43k; R_0603_1608Metric
R17, R24, R48, R51: 9.1k; R_0603_1608Metric
R18: 12k; R_0603_1608Metric
R19: 30k; R_0603_1608Metric
R20: 56k; R_0603_1608Metric
R22: 22k; R_0603_1608Metric
R25, R52: 18k; R_0603_1608Metric
R26, R29: 1k; R_0603_1608Metric
R27: 200; R_0603_1608Metric
R28, R35: 620; R_0603_1608Metric
R30: 2k; R_0603_1608Metric
R31: 430; R_0603_1608Metric
R32, R56: 820; R_0603_1608Metric
R33, R60: 1.6k; R_0603_1608Metric
R34, R61: 330; R_0603_1608Metric
R36: 120k; R_0603_1608Metric
R37, R44, R49, R71: 24k; R_0603_1608Metric
R38, R46, R53: 36k; R_0603_1608Metric
R39: 82k; R_0603_1608Metric
R40: 160k; R_0603_1608Metric
R42: 62k; R_0603_1608Metric
R43, R70: 130k; R_0603_1608Metric
R45, R72: 51k; R_0603_1608Metric
R47: 7.5k; R_0603_1608Metric
R54: 6.8k; R_0603_1608Metric
R57: 160; R_0603_1608Metric
R58: 470; R_0603_1608Metric
R59: 750; R_0603_1608Metric
R62: 680; R_0603_1608Metric
R63: 1.3k; R_0603_1608Metric
R64: 270; R_0603_1608Metric
R65: 510; R_0603_1608Metric
R67, R74: 20k; R_0603_1608Metric
R68: 27k; R_0603_1608Metric
R69: 68k; R_0603_1608Metric
R75: 39k; R_0603_1608Metric
RV1: 50k; Potentiometer_Alps_RK09K_Single_Vertical
SW1: 5FS1S102M2QE
U2: MC34063AD; SOIC-8_3.9x4.9mm_P1.27mm
U3: LM2576T-5; TO-220-5_P3.4x3.7mm_StaggerOdd_Lead3.8mm_Vertical
U4, U8, U9, U10: TL084CPW; TSSOP-14_4.4x5mm_P0.65mm
U5, U6, U7: MC33078D; SO-8_3.9x4.9mm_P1.27mm

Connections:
+5V: C19.1, C26.1, J4.6, J5.6, J6.6, J7.6, J8.6, J9.6, J10.6, J11.6, J12.6, J13.6, L3.2, R12.1
+12V: C1.1, C2.1, C3.1, C6.1, C8.1, C10.1, C12.1, C15.1, C20.1, C24.1, D3.1 (K), D4.2 (K), J4.4, J5.4, J6.4, J7.4, J8.4, J9.4, J10.4, J11.4, J12.4, J13.4, R3.2, U2.6 (Vin), U3.1 (VIN), U4.4 (V+), U5.8 (V+), U6.8 (V+), U7.8 (V+), U8.4 (V+), U9.4 (V+), U10.4 (V+)
-10V: C5.2, C7.2, C9.2, C11.2, C13.2, C16.2, C17.2, C21.2, C22.2, C25.2, D4.1 (A), D5.2 (A), J4.5, J5.5, J6.5, J7.5, J8.5, J9.5, J10.5, J11.5, J12.5, J13.5, R8.1, U2.4 (GND), U4.11 (V-), U5.4 (V-), U6.4 (V-), U7.4 (V-), U8.11 (V-), U9.11 (V-), U10.11 (V-)
GND: C1.2, C2.2, C3.2, C6.2, C7.1, C8.2, C9.1, C10.2, C11.1, C12.2, C13.1, C15.2, C16.1, C17.1, C19.2, C20.2, C21.1, C22.1, C24.2, C25.1, C26.2, D1.2 (A), D2.2 (A), J1.2, J2.1, J3.1, J4.2, J5.2, J6.2, J7.2, J8.2, J9.2, J10.2, J11.2, J12.2, J13.2, L1.2, R11.2, R13.2, R15.2, R26.1, R27.1, R28.1, R29.1, R30.1, R31.1, R32.1, R33.1, R34.1, R35.1, R56.1, R57.1, R58.1, R59.1, R60.1, R61.1, R62.1, R63.1, R64.1, R65.1, U3.3 (GND), U3.5 (~ON/OFF), U4.3 (+), U4.10 (+), U4.12 (+), U5.3 (+), U5.5 (+), U6.3 (+), U6.5 (+), U7.3 (+), U7.5 (+), U8.3 (+), U8.5 (+), U8.10 (+), U8.12 (+), U9.3 (+), U9.5 (+), U9.10 (+), U9.12 (+), U10.3 (+), U10.5 (+), U10.10 (+), U10.12 (+)
unnamed: C29.1, C39.1, R16.2, R26.2
unnamed: C30.1, C40.1, R17.2, R27.2
unnamed: C31.1, C41.1, R18.2, R28.2
unnamed: C32.1, C42.1, R19.2, R29.2
unnamed: C33.1, C43.1, R20.2, R30.2
unnamed: C34.1, C44.1, R21.2, R31.2
unnamed: C35.1, C45.1, R22.2, R32.2
unnamed: C36.1, C46.1, R23.2, R33.2
unnamed: C37.1, C47.1, R24.2, R34.2
unnamed: C38.1, C48.1, R25.2, R35.2
unnamed: C39.2, R36.2, R46.1, U5.1
unnamed: C40.2, R37.2, R47.1, U6.1
unnamed: C41.2, R38.2, R48.1, U7.1
unnamed: C42.2, R39.2, R49.1, U10.1
unnamed: C43.2, R40.2, R50.1, U10.14
unnamed: C44.2, R41.2, R51.1, U9.1
unnamed: C45.2, R42.2, R52.1, U9.8
unnamed: C46.2, R43.2, R53.1, U8.8
unnamed: C47.2, R44.2, R54.1, U8.14
unnamed: C48.2, R45.2, R55.1, U4.14
unnamed: C49.1, C59.1, R46.2, R56.2
unnamed: C50.1, C60.1, R47.2, R57.2
unnamed: C51.1, C61.1, R48.2, R58.2
unnamed: C52.1, C62.1, R49.2, R59.2
unnamed: C53.1, C63.1, R50.2, R60.2
unnamed: C54.1, C64.1, R51.2, R61.2
unnamed: C55.1, C65.1, R52.2, R62.2
unnamed: C56.1, C66.1, R53.2, R63.2
unnamed: C57.1, C67.1, R54.2, R64.2
unnamed: C58.1, C68.1, R55.2, R65.2
unnamed: D1.1 (K), D3.2 (A), F1.2
unnamed: D2.1 (K), L3.1, U3.2 (OUT)
unnamed: D4.3 (C), JP1.2 (B), JP2.2 (B), JP3.2 (B), R14.1, U4.2 (-)
unnamed: D5.1 (K), L1.1, U2.2 (SwE)
unnamed: J2.2, J3.2, R4.1, R6.1
unnamed: J2.5, J3.5, R5.1, R7.1
unnamed: C49.2, J4.1, R66.2, U5.7
unnamed: C50.2, J5.1, R67.2, U6.7
unnamed: C51.2, J6.1, R68.2, U7.7
unnamed: C52.2, J7.1, R69.2, U10.7
unnamed: C53.2, J8.1, R70.2, U10.8
unnamed: C54.2, J9.1, R71.2, U9.7
unnamed: C55.2, J10.1, R72.2, U9.14
unnamed: C56.2, J11.1, R73.2, U8.7
unnamed: C57.2, J12.1, R74.2, U8.1
unnamed: C58.2, J13.1, R75.2, U4.8
unnamed: JP1.1 (A), R4.2
unnamed: JP2.1 (A), R5.2
unnamed: JP3.1 (A), R6.2, R7.2
unnamed: R14.2, RV1.3
unnamed: R16.1, R17.1, R18.1, R19.1, R20.1, R21.1, R22.1, R23.1, R24.1, R25.1, RV1.1, RV1.2, U4.1
unnamed: F1.1, SW1.1 (A)
unnamed: J1.1, SW1.2 (B)
unnamed: R3.1, U2.1 (SwC), U2.7 (Ipk), U2.8 (DC)
unnamed: C5.1, U2.3 (TC)
unnamed: R8.2, R11.1, U2.5 (Vfb)
unnamed: R12.2, R13.1, U3.4 (FB)
unnamed: R15.1, U4.5 (+)
unnamed: U4.6 (-), U4.7
unnamed: C68.2, R75.1, U4.9 (-)
unnamed: C38.2, R45.1, U4.13 (-)
unnamed: C29.2, R36.1, U5.2 (-)
unnamed: C59.2, R66.1, U5.6 (-)
unnamed: C30.2, R37.1, U6.2 (-)
unnamed: C60.2, R67.1, U6.6 (-)
unnamed: C31.2, R38.1, U7.2 (-)
unnamed: C61.2, R68.1, U7.6 (-)
unnamed: C67.2, R74.1, U8.2 (-)
unnamed: C66.2, R73.1, U8.6 (-)
unnamed: C36.2, R43.1, U8.9 (-)
unnamed: C37.2, R44.1, U8.13 (-)
unnamed: C34.2, R41.1, U9.2 (-)
unnamed: C64.2, R71.1, U9.6 (-)
unnamed: C35.2, R42.1, U9.9 (-)
unnamed: C65.2, R72.1, U9.13 (-)
unnamed: C32.2, R39.1, U10.2 (-)
unnamed: C62.2, R69.1, U10.6 (-)
unnamed: C63.2, R70.1, U10.9 (-)
unnamed: C33.2, R40.1, U10.13 (-)

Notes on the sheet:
+5V
LINE OUT
GND
-10V
LINE IN
RIGHT
+12V
12V TO -15V CONVERTER
LEFT
AUDIO INPUT
Gain Control
BYPASSING
12V TO 5V CONVERTER
Needs to be -15V
Divider only for adj version
12V INPUT
POWER INPUT AND PROTECTION

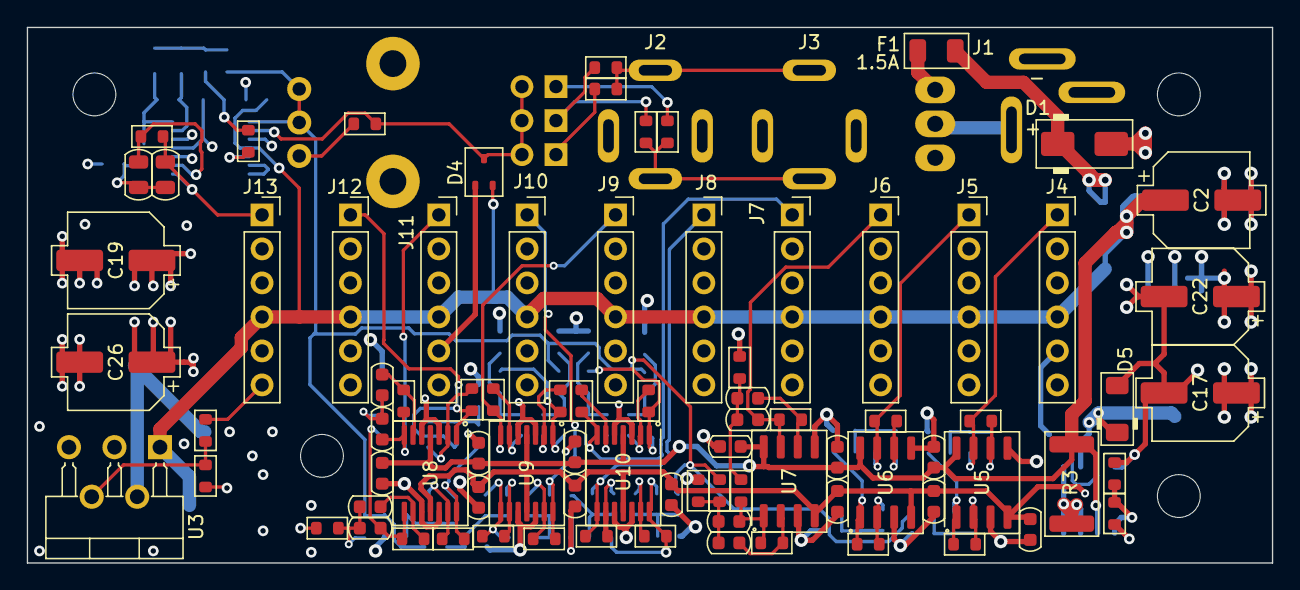
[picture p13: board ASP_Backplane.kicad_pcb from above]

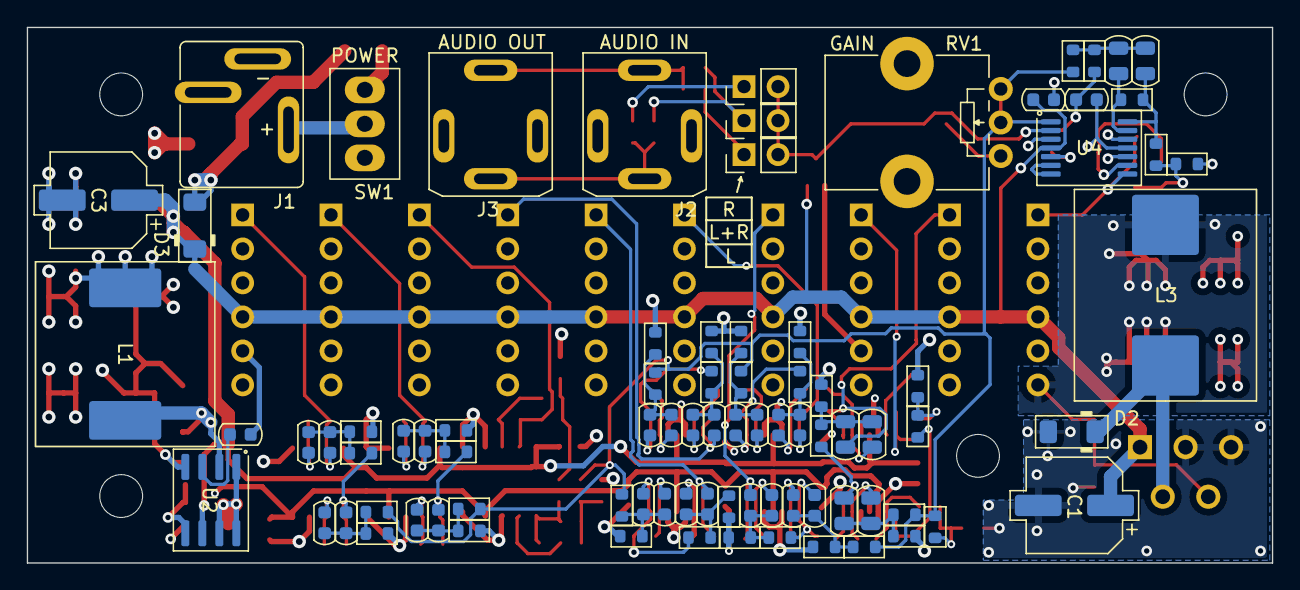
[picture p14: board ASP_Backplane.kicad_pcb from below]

Board: 4 copper layers, 93.0 x 40.0 mm, 168 parts (85 on the bottom side), 83 nets.

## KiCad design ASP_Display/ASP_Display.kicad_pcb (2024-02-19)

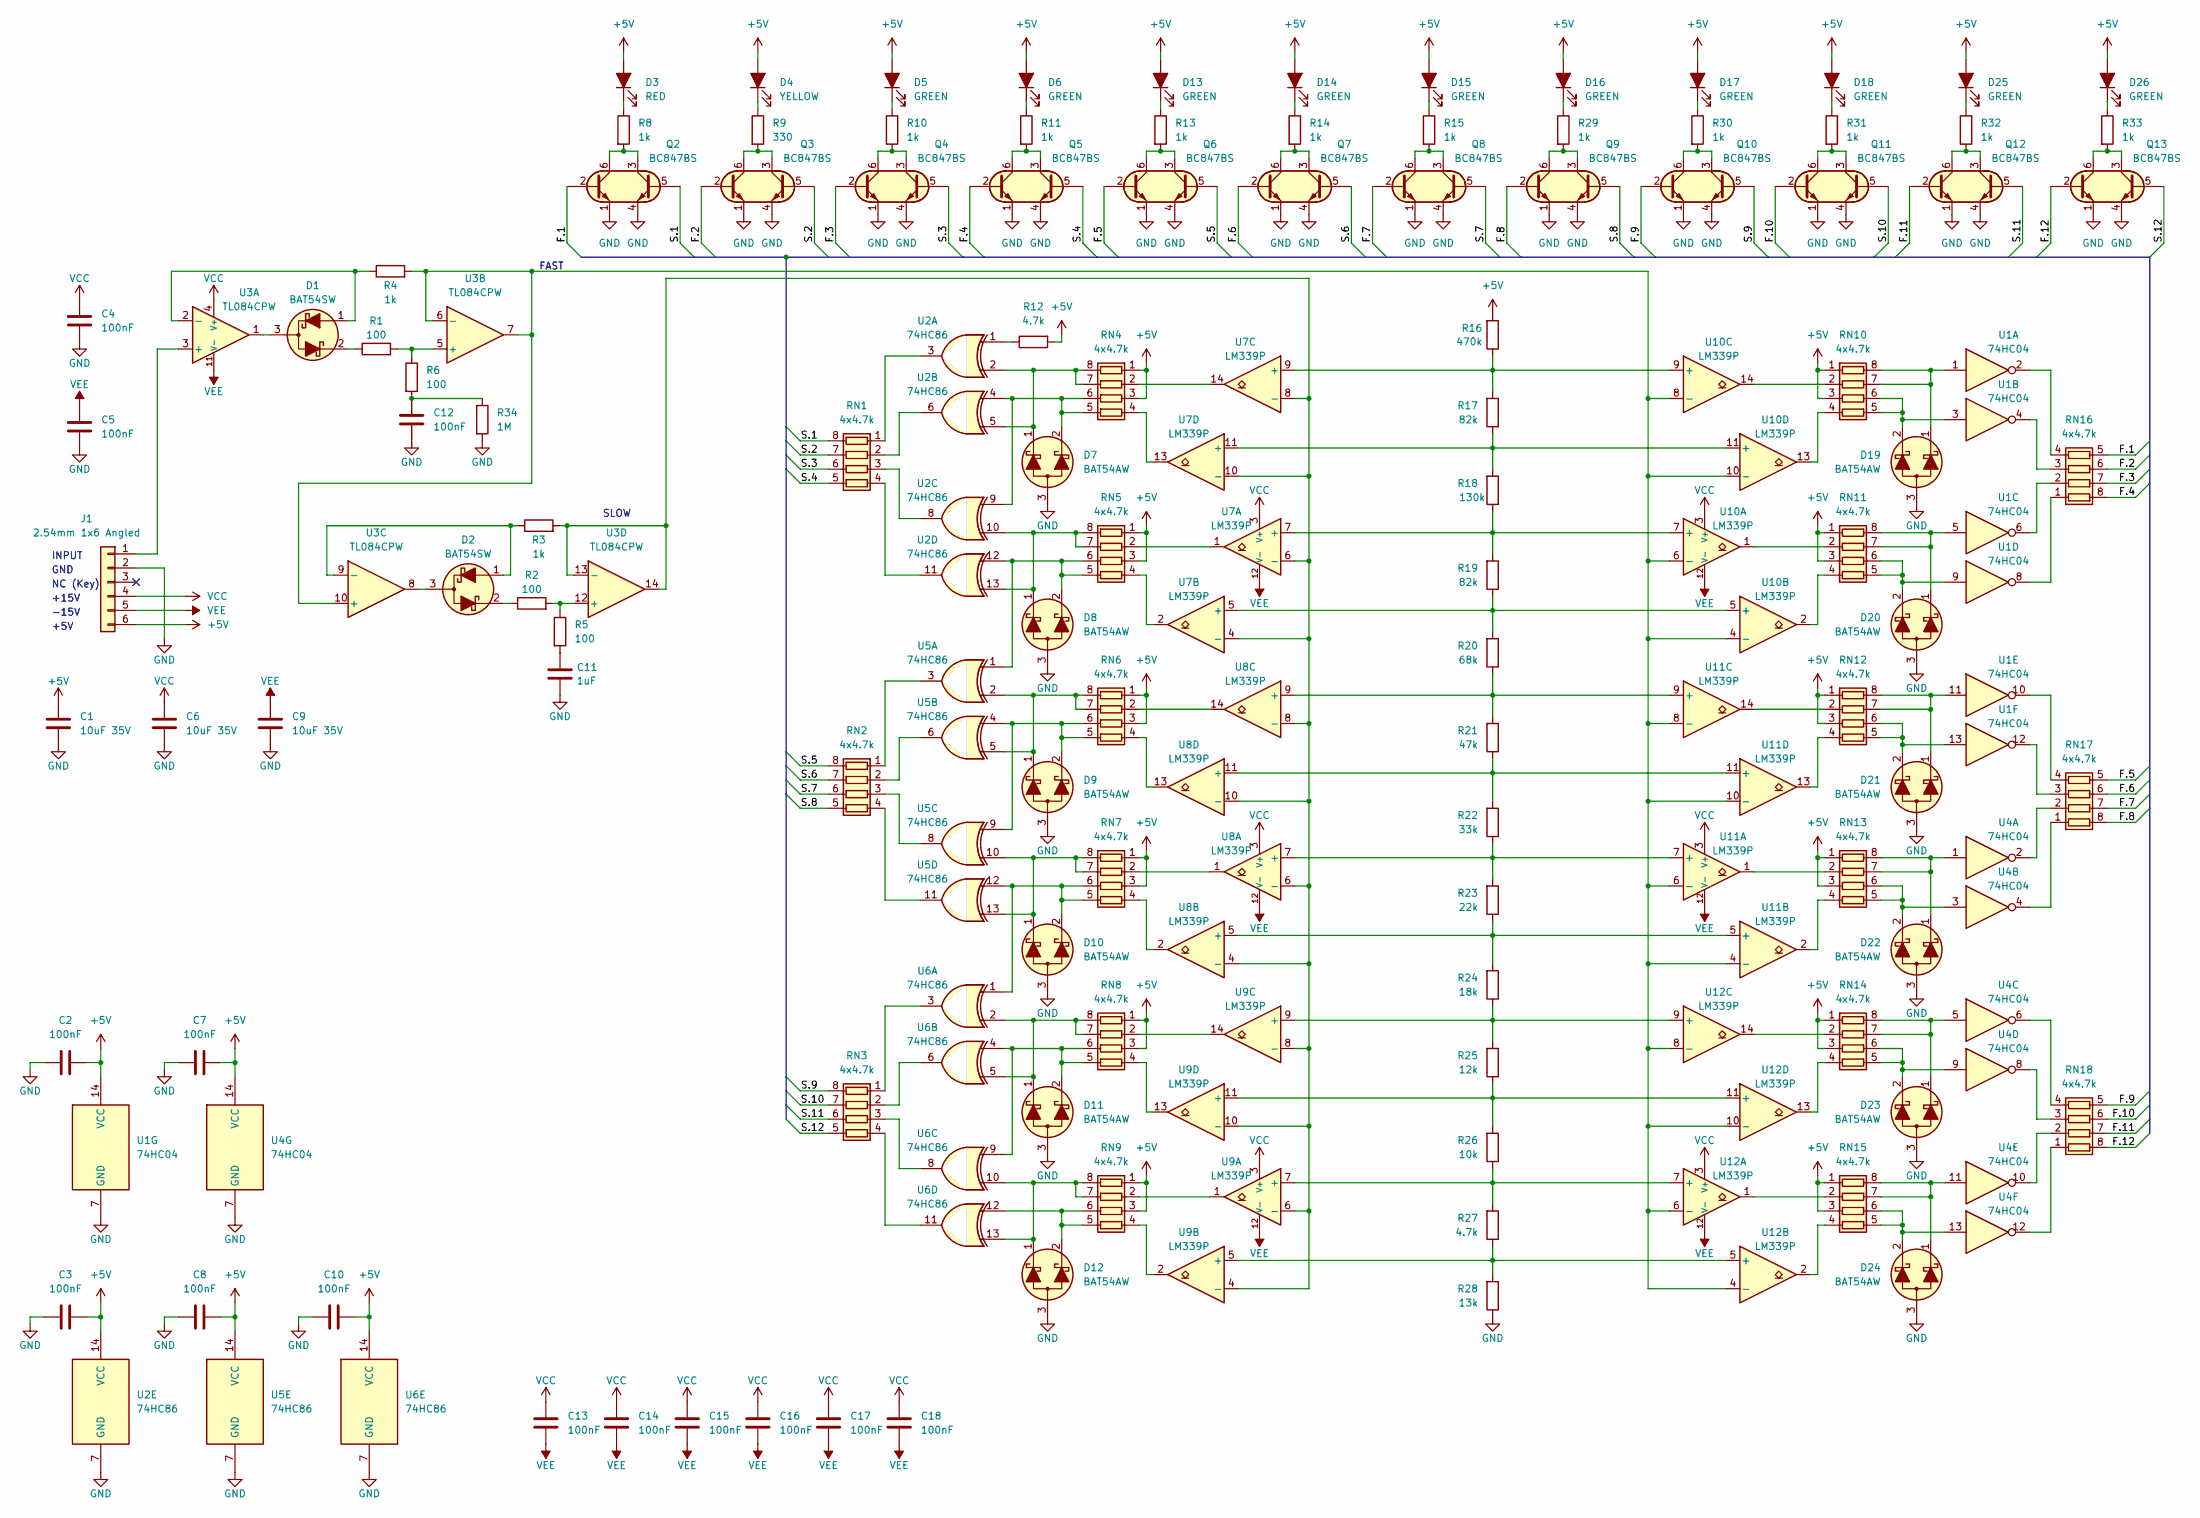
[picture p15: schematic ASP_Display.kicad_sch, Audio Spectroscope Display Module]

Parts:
C1, C6, C9: 10uF 35V; C_1206_3216Metric
C2, C3, C4, C5, C7, C8, C10, C12, C13, C14, C15, C16, C17, C18: 100nF; C_0603_1608Metric
C11: 1uF; C_0603_1608Metric
D1, D2: BAT54SW; SOT-323_SC-70
D3: RED; LED_Rectangular_W5.0mm_H2.0mm
D4: YELLOW; LED_Rectangular_W5.0mm_H2.0mm
D5, D6, D13, D14, D15, D16, D17, D18, D25, D26: GREEN; LED_Rectangular_W5.0mm_H2.0mm
D7, D8, D9, D10, D11, D12, D19, D20, D21, D22, D23, D24: BAT54AW; SOT-323_SC-70
J1: 2.54mm 1x6 Angled; PinHeader_1x06_P2.54mm_Horizontal
Q2, Q3, Q4, Q5, Q6, Q7, Q8, Q9, Q10, Q11, Q12, Q13: BC847BS; SOT-363_SC-70-6
R1, R2, R5, R6: 100; R_0603_1608Metric
R3, R4: 1k; R_0603_1608Metric
R8, R10, R11, R13, R14, R15, R29, R30, R31, R32, R33: 1k; R_0805_2012Metric
R9: 330; R_0805_2012Metric
R12, R27: 4.7k; R_0603_1608Metric
R16: 470k; R_0603_1608Metric
R17, R19: 82k; R_0603_1608Metric
R18: 130k; R_0603_1608Metric
R20: 68k; R_0603_1608Metric
R21: 47k; R_0603_1608Metric
R22: 33k; R_0603_1608Metric
R23: 22k; R_0603_1608Metric
R24: 18k; R_0603_1608Metric
R25: 12k; R_0603_1608Metric
R26: 10k; R_0603_1608Metric
R28: 13k; R_0603_1608Metric
R34: 1M; R_0603_1608Metric
RN1, RN2, RN3, RN4, RN5, RN6, RN7, RN8, RN9, RN10, RN11, RN12, RN13, RN14, RN15, RN16, RN17, RN18: 4x4.7k; R_Array_Convex_4x0603
U1, U4: 74HC04; TSSOP-14_4.4x5mm_P0.65mm
U2, U5, U6: 74HC86; TSSOP-14_4.4x5mm_P0.65mm
U3: TL084CPW; TSSOP-14_4.4x5mm_P0.65mm
U7, U8, U9, U10, U11, U12: LM339P; TSSOP-14_4.4x5mm_P0.65mm

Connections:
+5V: C1.1, C2.1, C3.1, C7.1, C8.1, C10.1, D3.2 (A), D4.2 (A), D5.2 (A), D6.2 (A), D13.2 (A), D14.2 (A), D15.2 (A), D16.2 (A), D17.2 (A), D18.2 (A), D25.2 (A), D26.2 (A), J1.6, R12.2, R16.2, RN4.1 (R1.1), RN4.3 (R3.1), RN5.1 (R1.1), RN5.3 (R3.1), RN6.1 (R1.1), RN6.3 (R3.1), RN7.1 (R1.1), RN7.3 (R3.1), RN8.1 (R1.1), RN8.3 (R3.1), RN9.1 (R1.1), RN9.3 (R3.1), RN10.1 (R1.1), RN10.3 (R3.1), RN11.1 (R1.1), RN11.3 (R3.1), RN12.1 (R1.1), RN12.3 (R3.1), RN13.1 (R1.1), RN13.3 (R3.1), RN14.1 (R1.1), RN14.3 (R3.1), RN15.1 (R1.1), RN15.3 (R3.1), U1.14 (VCC), U2.14 (VCC), U4.14 (VCC), U5.14 (VCC), U6.14 (VCC)
/F.1: Q2.2 (B1), RN16.5 (R4.2)
/F.2: Q3.2 (B1), RN16.6 (R3.2)
/F.3: Q4.2 (B1), RN16.7 (R2.2)
/F.4: Q5.2 (B1), RN16.8 (R1.2)
/F.5: Q6.2 (B1), RN17.5 (R4.2)
/F.6: Q7.2 (B1), RN17.6 (R3.2)
/F.7: Q8.2 (B1), RN17.7 (R2.2)
/F.8: Q9.2 (B1), RN17.8 (R1.2)
/F.9: Q10.2 (B1), RN18.5 (R4.2)
/F.10: Q11.2 (B1), RN18.6 (R3.2)
/F.11: Q12.2 (B1), RN18.7 (R2.2)
/F.12: Q13.2 (B1), RN18.8 (R1.2)
/S.1: Q2.5 (B2), RN1.8 (R1.2)
/S.2: Q3.5 (B2), RN1.7 (R2.2)
/S.3: Q4.5 (B2), RN1.6 (R3.2)
/S.4: Q5.5 (B2), RN1.5 (R4.2)
/S.5: Q6.5 (B2), RN2.8 (R1.2)
/S.6: Q7.5 (B2), RN2.7 (R2.2)
/S.7: Q8.5 (B2), RN2.6 (R3.2)
/S.8: Q9.5 (B2), RN2.5 (R4.2)
/S.9: Q10.5 (B2), RN3.8 (R1.2)
/S.10: Q11.5 (B2), RN3.7 (R2.2)
/S.11: Q12.5 (B2), RN3.6 (R3.2)
/S.12: Q13.5 (B2), RN3.5 (R4.2)
GND: C1.2, C2.2, C3.2, C4.1, C5.1, C6.2, C7.2, C8.2, C9.2, C10.2, C11.1, C12.1, D7.3 (A), D8.3 (A), D9.3 (A), D10.3 (A), D11.3 (A), D12.3 (A), D19.3 (A), D20.3 (A), D21.3 (A), D22.3 (A), D23.3 (A), D24.3 (A), J1.2, Q2.1 (E1), Q2.4 (E2), Q3.1 (E1), Q3.4 (E2), Q4.1 (E1), Q4.4 (E2), Q5.1 (E1), Q5.4 (E2), Q6.1 (E1), Q6.4 (E2), Q7.1 (E1), Q7.4 (E2), Q8.1 (E1), Q8.4 (E2), Q9.1 (E1), Q9.4 (E2), Q10.1 (E1), Q10.4 (E2), Q11.1 (E1), Q11.4 (E2), Q12.1 (E1), Q12.4 (E2), Q13.1 (E1), Q13.4 (E2), R28.1, R34.2, U1.7 (GND), U2.7 (GND), U4.7 (GND), U5.7 (GND), U6.7 (GND)
unnamed: C11.2, R5.2
unnamed: C12.2, R6.2, R34.1
unnamed: D1.1 (A), R4.1, U3.2 (-)
unnamed: D1.3 (C), U3.1
unnamed: D1.2 (K), R1.1
unnamed: D2.1 (A), R3.1, U3.9 (-)
unnamed: D2.3 (C), U3.8
unnamed: D2.2 (K), R2.1
unnamed: D3.1 (K), R8.1
unnamed: D4.1 (K), R9.1
unnamed: D5.1 (K), R10.1
unnamed: D6.1 (K), R11.1
unnamed: D7.1 (K1), RN4.7 (R2.2), RN4.8 (R1.2), U2.2, U2.5
unnamed: D7.2 (K2), RN4.5 (R4.2), RN4.6 (R3.2), U2.4, U2.9
unnamed: D8.1 (K1), RN5.7 (R2.2), RN5.8 (R1.2), U2.10, U2.13
unnamed: D8.2 (K2), RN5.5 (R4.2), RN5.6 (R3.2), U2.12, U5.1
unnamed: D9.1 (K1), RN6.7 (R2.2), RN6.8 (R1.2), U5.2, U5.5
unnamed: D9.2 (K2), RN6.5 (R4.2), RN6.6 (R3.2), U5.4, U5.9
unnamed: D10.1 (K1), RN7.7 (R2.2), RN7.8 (R1.2), U5.10, U5.13
unnamed: D10.2 (K2), RN7.5 (R4.2), RN7.6 (R3.2), U5.12, U6.1
unnamed: D11.1 (K1), RN8.7 (R2.2), RN8.8 (R1.2), U6.2, U6.5
unnamed: D11.2 (K2), RN8.5 (R4.2), RN8.6 (R3.2), U6.4, U6.9
unnamed: D12.1 (K1), RN9.7 (R2.2), RN9.8 (R1.2), U6.10, U6.13
unnamed: D12.2 (K2), RN9.5 (R4.2), RN9.6 (R3.2), U6.12
unnamed: D13.1 (K), R13.1
unnamed: D14.1 (K), R14.1
unnamed: D15.1 (K), R15.1
unnamed: D16.1 (K), R29.1
unnamed: D17.1 (K), R30.1
unnamed: D18.1 (K), R31.1
unnamed: D19.1 (K1), RN10.7 (R2.2), RN10.8 (R1.2), U1.1
unnamed: D19.2 (K2), RN10.5 (R4.2), RN10.6 (R3.2), U1.3
unnamed: D20.1 (K1), RN11.7 (R2.2), RN11.8 (R1.2), U1.5
unnamed: D20.2 (K2), RN11.5 (R4.2), RN11.6 (R3.2), U1.9
unnamed: D21.1 (K1), RN12.7 (R2.2), RN12.8 (R1.2), U1.11
unnamed: D21.2 (K2), RN12.5 (R4.2), RN12.6 (R3.2), U1.13
unnamed: D22.1 (K1), RN13.7 (R2.2), RN13.8 (R1.2), U4.1
unnamed: D22.2 (K2), RN13.5 (R4.2), RN13.6 (R3.2), U4.3
unnamed: D23.1 (K1), RN14.7 (R2.2), RN14.8 (R1.2), U4.5
unnamed: D23.2 (K2), RN14.5 (R4.2), RN14.6 (R3.2), U4.9
unnamed: D24.1 (K1), RN15.7 (R2.2), RN15.8 (R1.2), U4.11
unnamed: D24.2 (K2), RN15.5 (R4.2), RN15.6 (R3.2), U4.13
unnamed: D25.1 (K), R32.1
unnamed: D26.1 (K), R33.1
unnamed: J1.1, U3.3 (+)
unnamed: Q2.3 (C2), Q2.6 (C1), R8.2
unnamed: Q3.3 (C2), Q3.6 (C1), R9.2
unnamed: Q4.3 (C2), Q4.6 (C1), R10.2
unnamed: Q5.3 (C2), Q5.6 (C1), R11.2
unnamed: Q6.3 (C2), Q6.6 (C1), R13.2
unnamed: Q7.3 (C2), Q7.6 (C1), R14.2
unnamed: Q8.3 (C2), Q8.6 (C1), R15.2
unnamed: Q9.3 (C2), Q9.6 (C1), R29.2
unnamed: Q10.3 (C2), Q10.6 (C1), R30.2
unnamed: Q11.3 (C2), Q11.6 (C1), R31.2
unnamed: Q12.3 (C2), Q12.6 (C1), R32.2
unnamed: Q13.3 (C2), Q13.6 (C1), R33.2
unnamed: R12.1, U2.1
unnamed: RN1.1 (R1.1), U2.3
unnamed: RN1.2 (R2.1), U2.6
unnamed: RN1.3 (R3.1), U2.8
unnamed: RN1.4 (R4.1), U2.11
unnamed: RN2.1 (R1.1), U5.3
unnamed: RN2.2 (R2.1), U5.6
unnamed: RN2.3 (R3.1), U5.8
unnamed: RN2.4 (R4.1), U5.11
unnamed: RN3.1 (R1.1), U6.3
unnamed: RN3.2 (R2.1), U6.6
unnamed: RN3.3 (R3.1), U6.8
unnamed: RN3.4 (R4.1), U6.11
unnamed: RN4.2 (R2.1), U7.14
unnamed: RN4.4 (R4.1), U7.13
unnamed: RN5.2 (R2.1), U7.1
unnamed: RN5.4 (R4.1), U7.2
unnamed: RN6.2 (R2.1), U8.14
unnamed: RN6.4 (R4.1), U8.13
unnamed: RN7.2 (R2.1), U8.1
unnamed: RN7.4 (R4.1), U8.2
unnamed: RN8.2 (R2.1), U9.14
unnamed: RN8.4 (R4.1), U9.13
unnamed: RN9.2 (R2.1), U9.1
unnamed: RN9.4 (R4.1), U9.2
unnamed: RN10.2 (R2.1), U10.14
unnamed: RN10.4 (R4.1), U10.13
unnamed: RN11.2 (R2.1), U10.1
unnamed: RN11.4 (R4.1), U10.2
unnamed: RN12.2 (R2.1), U11.14
unnamed: RN12.4 (R4.1), U11.13
unnamed: RN13.2 (R2.1), U11.1
unnamed: RN13.4 (R4.1), U11.2
unnamed: RN14.2 (R2.1), U12.14
unnamed: RN14.4 (R4.1), U12.13
unnamed: RN15.2 (R2.1), U12.1
unnamed: RN15.4 (R4.1), U12.2
unnamed: RN16.1 (R1.1), U1.8
unnamed: RN16.2 (R2.1), U1.6
unnamed: RN16.3 (R3.1), U1.4
unnamed: RN16.4 (R4.1), U1.2
unnamed: RN17.1 (R1.1), U4.4
unnamed: RN17.2 (R2.1), U4.2
unnamed: RN17.3 (R3.1), U1.12
unnamed: RN17.4 (R4.1), U1.10
unnamed: RN18.1 (R1.1), U4.12
unnamed: RN18.2 (R2.1), U4.10
unnamed: RN18.3 (R3.1), U4.8
unnamed: RN18.4 (R4.1), U4.6
unnamed: R1.2, R6.1, U3.5 (+)
unnamed: R2.2, R5.1, U3.12 (+)
unnamed: R3.2, U3.13 (-), U3.14, U7.4 (-), U7.6 (-), U7.8 (-), U7.10 (-), U8.4 (-), U8.6 (-), U8.8 (-), U8.10 (-), U9.4 (-), U9.6 (-), U9.8 (-), U9.10 (-)
unnamed: R18.1, R19.2, U7.7 (+), U10.7 (+)
unnamed: R4.2, U3.6 (-), U3.7, U3.10 (+), U10.4 (-), U10.6 (-), U10.8 (-), U10.10 (-), U11.4 (-), U11.6 (-), U11.8 (-), U11.10 (-), U12.4 (-), U12.6 (-), U12.8 (-), U12.10 (-)
unnamed: R19.1, R20.2, U7.5 (+), U10.5 (+)
unnamed: R16.1, R17.2, U7.9 (+), U10.9 (+)
unnamed: R17.1, R18.2, U7.11 (+), U10.11 (+)
unnamed: R22.1, R23.2, U8.7 (+), U11.7 (+)
unnamed: R23.1, R24.2, U8.5 (+), U11.5 (+)
unnamed: R20.1, R21.2, U8.9 (+), U11.9 (+)
unnamed: R21.1, R22.2, U8.11 (+), U11.11 (+)
unnamed: R26.1, R27.2, U9.7 (+), U12.7 (+)
unnamed: R27.1, R28.2, U9.5 (+), U12.5 (+)
unnamed: R24.1, R25.2, U9.9 (+), U12.9 (+)
unnamed: R25.1, R26.2, U9.11 (+), U12.11 (+)
VCC: C4.2, C6.1, C13.2, C14.2, C15.2, C16.2, C17.2, C18.2, J1.4, U3.4 (V+), U7.3 (V+), U8.3 (V+), U9.3 (V+), U10.3 (V+), U11.3 (V+), U12.3 (V+)
VEE: C5.2, C9.1, C13.1, C14.1, C15.1, C16.1, C17.1, C18.1, J1.5, U3.11 (V-), U7.12 (V-), U8.12 (V-), U9.12 (V-), U10.12 (V-), U11.12 (V-), U12.12 (V-)

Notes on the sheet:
-15V
GND
NC (Key)
+15V
FAST
+5V
INPUT
SLOW

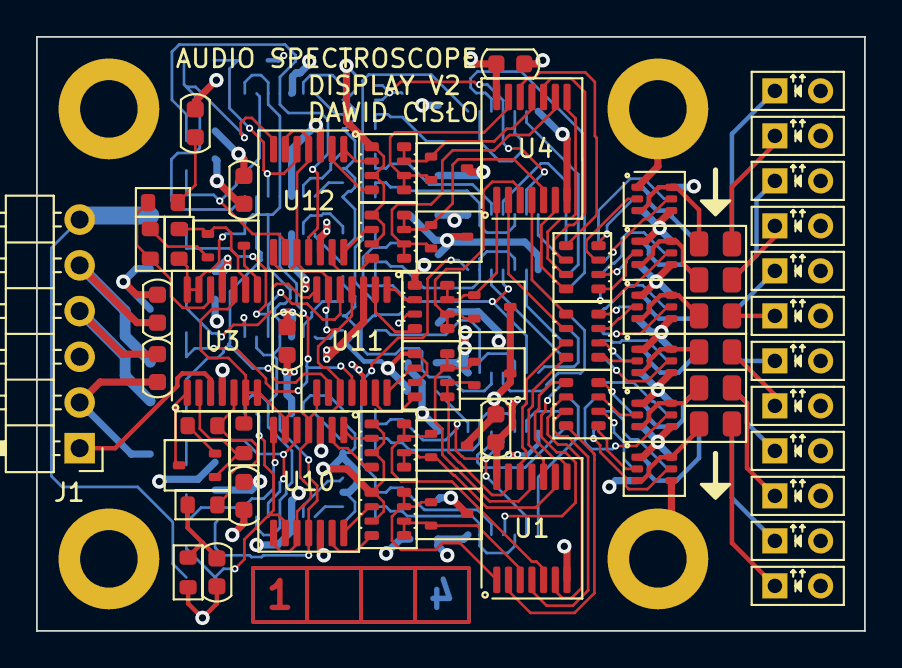
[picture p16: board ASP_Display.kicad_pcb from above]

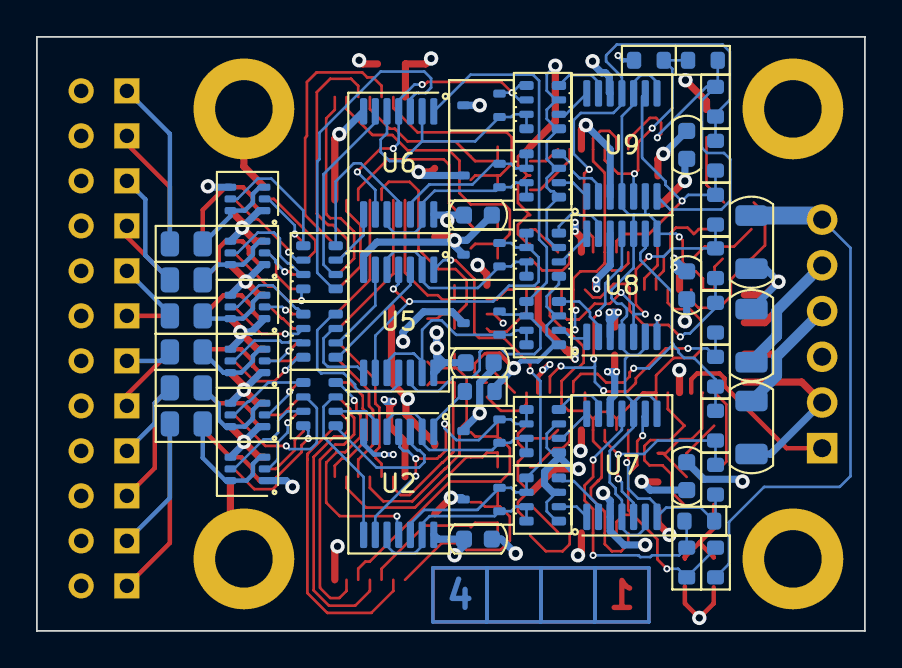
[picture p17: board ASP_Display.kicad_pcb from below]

Board: 4 copper layers, 46.0 x 33.0 mm, 120 parts (56 on the bottom side), 150 nets.

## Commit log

2024-02-19 Initial Commit
    Added main project files
    [ASP_BPN_PSU.kicad_sch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]
2024-02-19 Update BOM and PDF documentation
    [BOM.xlsx]
2024-02-20 Add documentation pictures
    [ASP_Backplane.kicad_sch]
